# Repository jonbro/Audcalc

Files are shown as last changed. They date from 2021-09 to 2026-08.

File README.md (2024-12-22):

# AudCalc

a pocket sized groovebox.

## Note to folks stumbing across this repo.

I'm happy with this, but its not 100% feature complete on the firmware side. Its really neat though, and I think you'll like it.

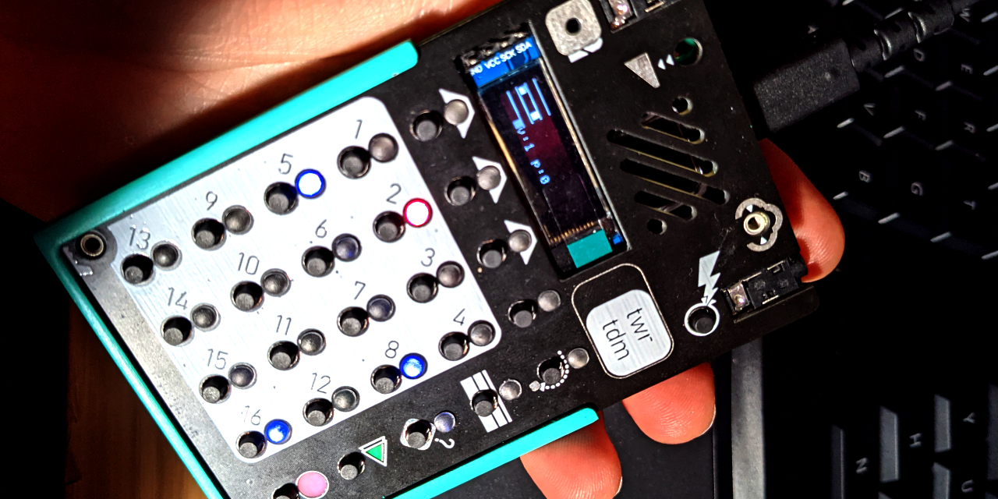
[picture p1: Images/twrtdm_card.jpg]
prototype v6

*v5 prototype*

- RP2040
- 1/8in audio i/o
- onboard mic
- 104mm x 68mm x 14mm

The bom is contained within the Hardware kicad project, ready for assembly via jlcpcb.
There are several additional items that must be sourced and handsoldered:

| part | count | mfg part number | link | notes |
|---|---|---|---|---|
| battery connector | 1 | jst s2b-ph-sm4-tb | https://octopart.com/s2b-ph-sm4-tb%28lf%29%28sn%29-jst-248913 | these are redibly available from aliexpress as well |
| midi / audio jacks | 4 | PJ-327C-4A | https://lcsc.com/product-detail/Audio-Connectors_Korean-Hroparts-Elec-PJ-327C-4A_C145813.html | I believe there is an equivalent CUI headphone jack. I'm using this cheaper version |
| pots | 2 | alps RK09K1130A5R | https://lcsc.com/product-detail/Variable-Resistors-Potentiometers_ALPSALPINE-RK09K1130A5R_C209779.html | |
| oled screen (128x32) | 1 | ssd1306 | https://www.aliexpress.com/item/4000842671330.html | I'm using the white / solderable version. |
| battery | 1 | lp-503562 | https://www.adafruit.com/product/258 | There are other cheaper sources for these. Confirm the correct polarity before using. |
| m2 4mm f-f standoff | 4 | | https://www.aliexpress.com/item/1005002145042844.html | |
| m2 6mm m-f standoff | 4 | | https://www.aliexpress.com/item/1005002145042844.html | |
| m2 3mm hex head bolt (black) | 8 | | https://www.aliexpress.com/item/10000148429238.html | |

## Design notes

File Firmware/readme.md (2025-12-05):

`openocd -f interface/picoprobe.cfg -f target/rp2040.cfg -s tcl`
`cmake -G"NMake Makefiles" ..`
run vscode in developer / admistrator mode for access to nmake (developer command prompt for vs 2019)
check to make sure the "kit" is selected (`GCC for arm-none-eabi 10.2.1`)

picotool save -r 0x10040000 0x11000000 
0x40000 
0x1000000
see this as an option for installing the toolchain
https://github.com/ndabas/pico-setup-windows

<!-- *Resource Generation* -->
`>C:\Python27\python.exe resources_compiler.py resources/resources.py`

*NanoPB generation* 
`python nanopb\generator\nanopb_generator.py VoiceData.proto`
note the forward slashes, it does some kind of replacement on the path to convert to a module name

rates 2x 3/2x 1x 3/4x (triplets) 1/2x 1/4x 1/8x

we want to count up to 0xffffff 8 times per second? at 120bpm

sixteents per second, thirty seconds per second

bpm to bps = 
120 * (1 / 60) * (1/4)

bps to 32nds p sec

bps * 1/8

beats per sample

44100 * 32nds p sec

    "1:1", 1
    
    "1:2", 2
    "2:2", 3 (2*1)
    
    "1:3", 4
    "2:3", 5 
    "1:3", 6 (3*2)

    "1:4", 7
    "2:4", 8
    "3:4", 9
    "4:4", 10 (5*2)
  e

2,756.25
q8          q4
(44100<<8)/(60<<4) = q4

60*32 = 1920

local valTable = {}

for i=2,8 do
  for j=1,i do
   table.insert(valTable, j)
   table.insert(valTable, i)
  end
end

print("const uint8_t ConditionalEvery[".. #valTable .. "] = {\n" .. table.concat(valTable, ", ") .. "};")

        // simplify, lets load from a known good source
        uint32_t filesize = ((uint32_t*)AudioSampleSecondbloop)[0]&0xffffff;
        int16_t* wave = ((int16_t*)AudioSampleSecondbloop)+2;
        if(filesize == 0 || sampleSegment == SMP_COMPLETE)
        {
            memset(buffer, 0, SAMPLES_PER_BUFFER*2);
            return;
        }
        if(sampleOffset > filesize)
            sampleSegment = SMP_COMPLETE;
        if(sampleSegment == SMP_COMPLETE)
            return;
        for(int i=0;i<SAMPLES_PER_BUFFER;i++)
        {
            if(sampleOffset > filesize - 1)
            {
                sampleSegment = SMP_COMPLETE;
            }
            // int16_t wave;
            // ffs_seek(GetFilesystem(), file, sampleOffset*2);
            // ffs_read(GetFilesystem(), file, wave, 2);

            phase_ += phase_increment;
            sampleOffset+=(phase_>>25);
            phase_-=(phase_&(0xfe<<24));

            buffer[i] = wave[sampleOffset];
            
        }
        return;

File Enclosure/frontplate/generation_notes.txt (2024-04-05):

### Frontplate generation notes

sorry, non free software. Hopefully it keeps working for a while. I'll include SVGs of the frontplate so it can continue to be edited.

export the mask and silkscreen groups to pngs that are 5119x7875 (aka 2000dpi)

import into kicad using the image converter tool. Use the output size settings  to 65mm / 100.1mm (set lock height width ratio).

for both images, you will need to use the "negative" button to invert correctly.

in the pcb editor, double click on the footprints, then update from library. You may need to disable layers so you can correctly double click on the soldermask footprint.

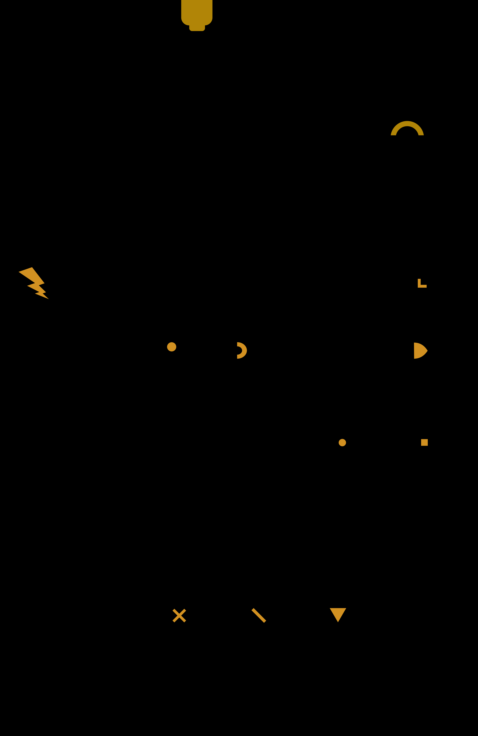
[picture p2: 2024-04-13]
Enclosure/frontplate/frontplate_mask.png

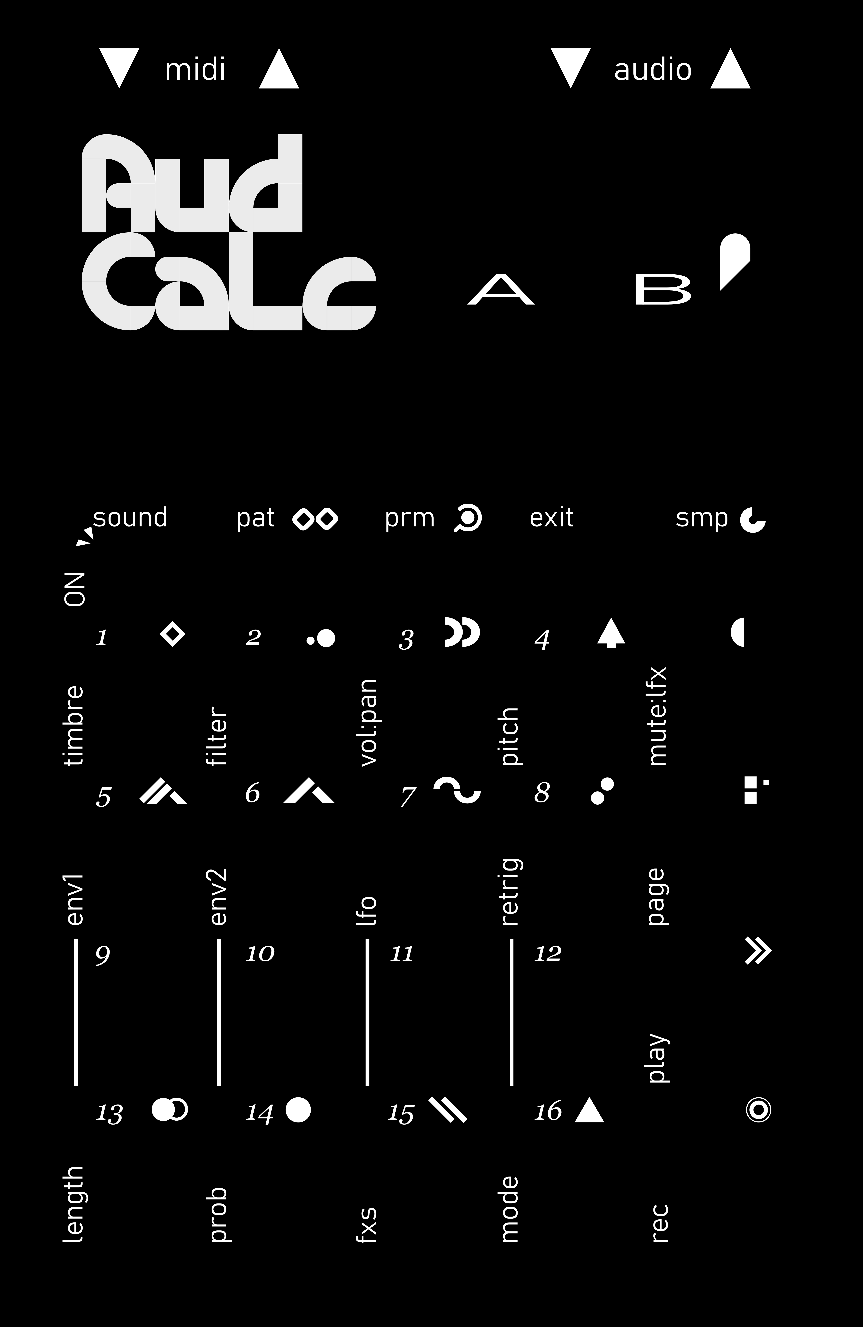
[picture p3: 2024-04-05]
Enclosure/frontplate/frontplate_silk.png

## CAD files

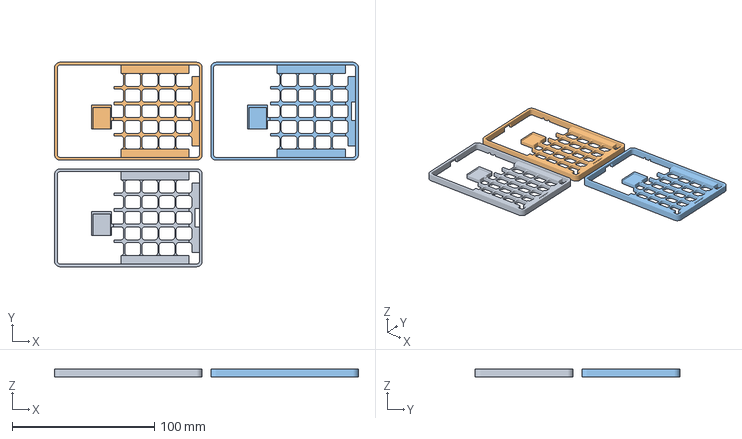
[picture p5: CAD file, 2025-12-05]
Enclosure/printedParts/FrontEnclosure.3mf
214.0 x 144.0 x 5.60 mm

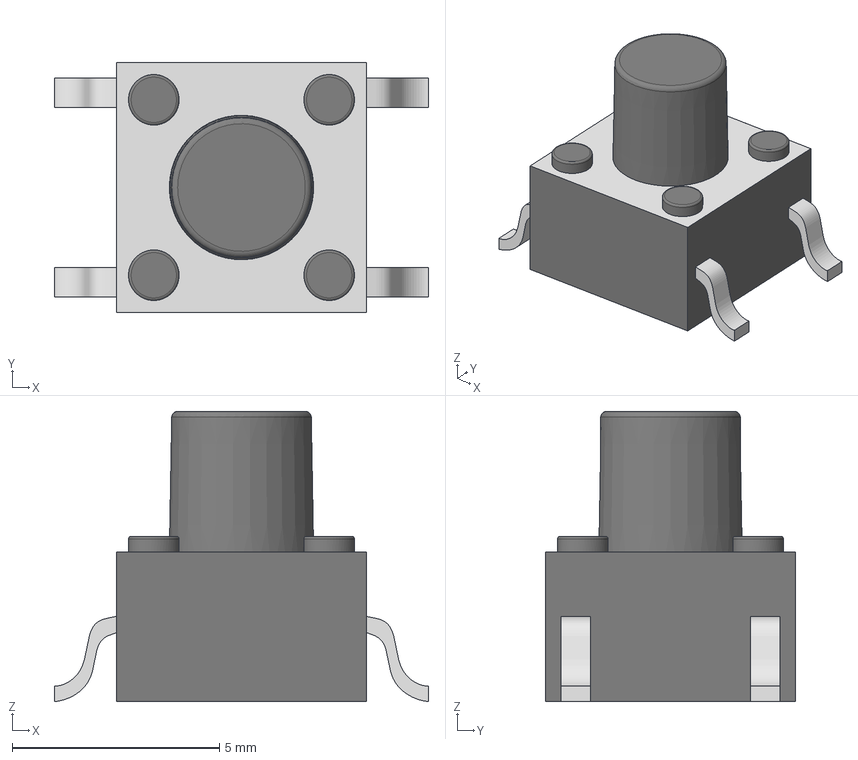
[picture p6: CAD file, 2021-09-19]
Hardware/audcalc/step/Tactal Switch - SMD (6mmx 6mmx 7mm) - Marked.stp
9.02 x 6.03 x 7.00 mm

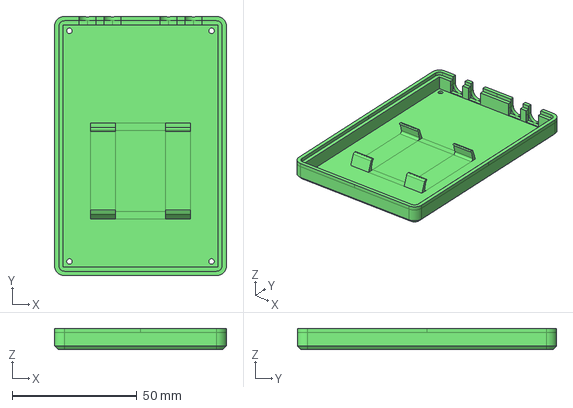
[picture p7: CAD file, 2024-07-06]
Enclosure/printedParts/BackEnclosure.FCStd
69.0 x 104.0 x 8.60 mm

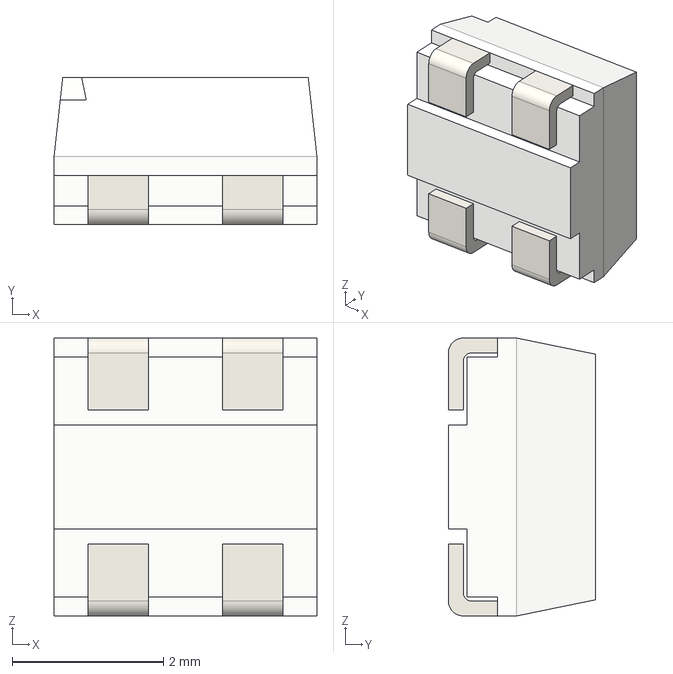
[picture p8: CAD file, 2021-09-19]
Hardware/audcalc/step/SMD WS2812B Mini.step
3.48 x 1.95 x 3.68 mm

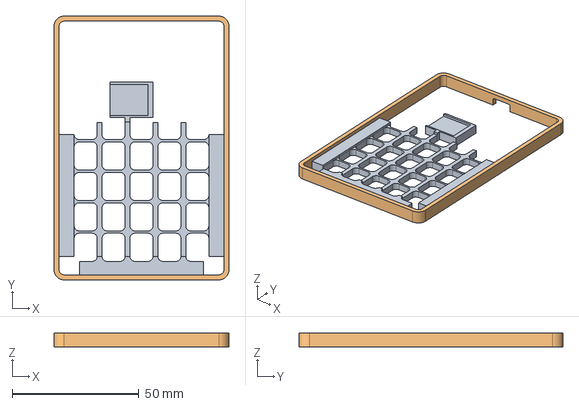
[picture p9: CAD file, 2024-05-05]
Enclosure/printedParts/baffles.FCStd
69.0 x 104.0 x 5.60 mm
baffles screenholder tolerance
outerBorderUsbClip

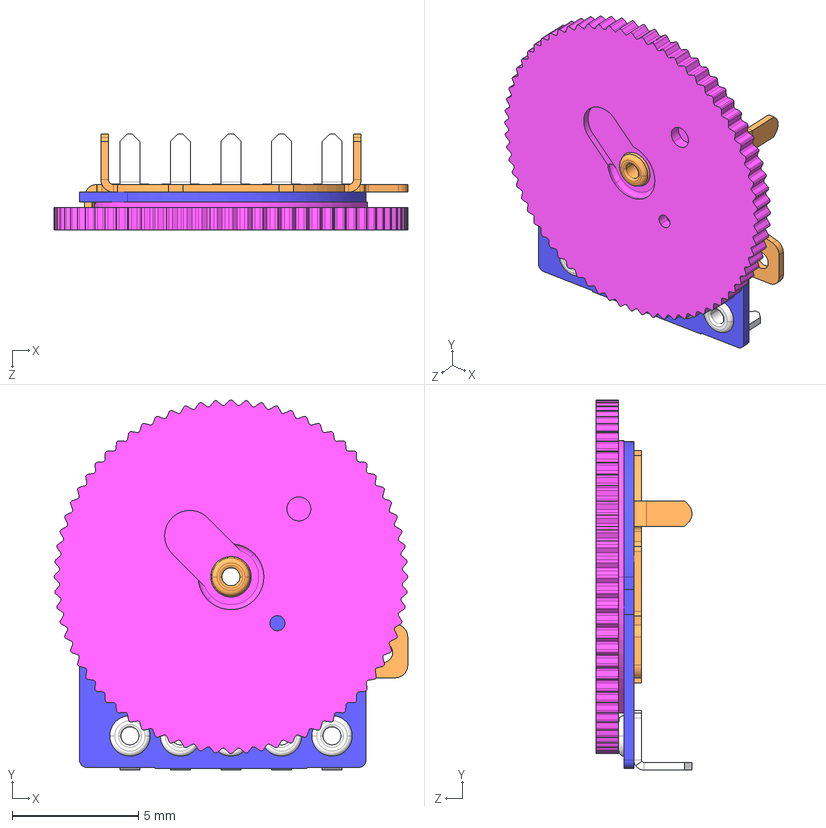
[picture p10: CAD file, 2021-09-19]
Hardware/audcalc/step/RK10J1_E.STEP
14.0 x 14.6 x 3.80 mm

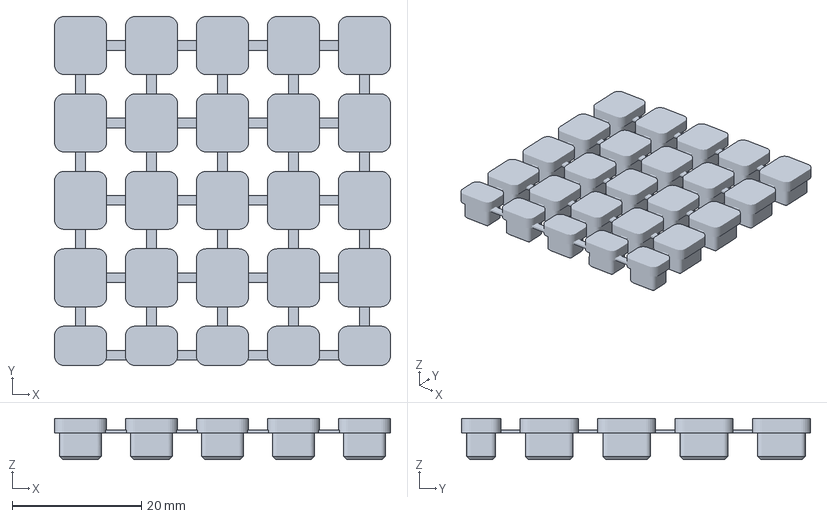
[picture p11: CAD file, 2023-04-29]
Enclosure/printedParts/Buttons.3mf
52.1 x 54.1 x 6.40 mm

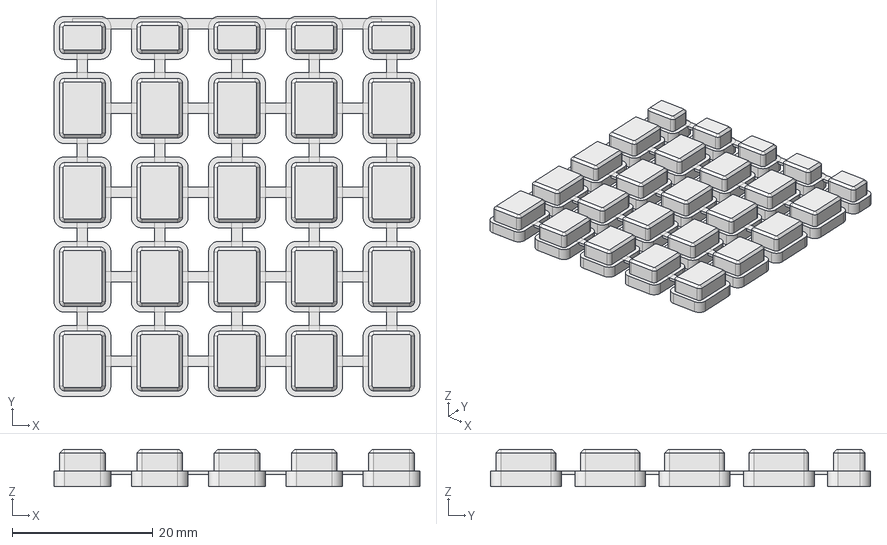
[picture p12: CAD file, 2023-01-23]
Enclosure/printedParts/printedParts-ButtonFrontExtrude.step
52.1 x 54.1 x 5.30 mm

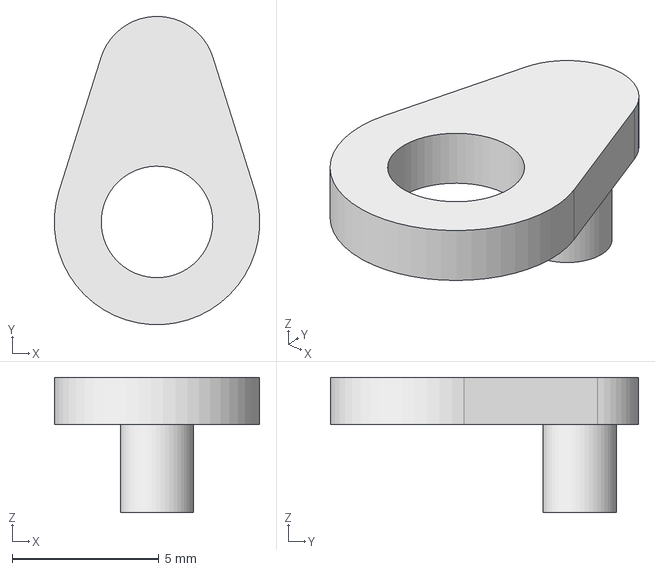
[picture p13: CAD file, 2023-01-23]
Enclosure/printedParts/buttonSurround.step
6.99 x 10.5 x 4.60 mm

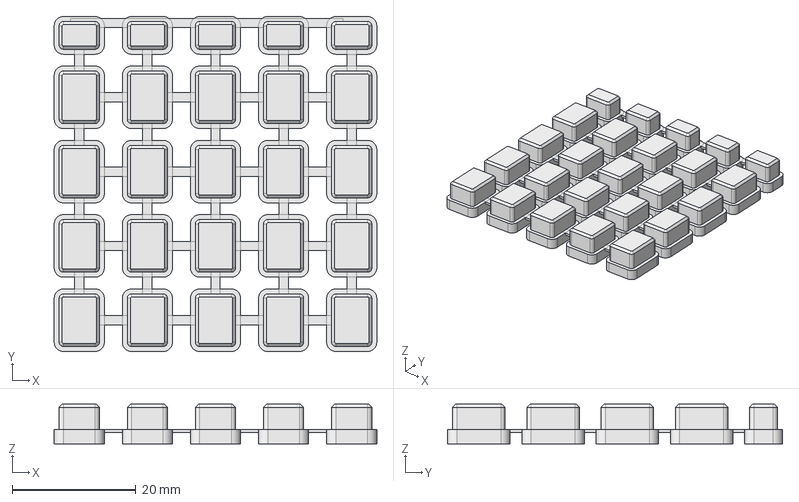
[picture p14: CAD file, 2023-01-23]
Enclosure/printedParts/printedParts-ButtonFrontExtrude-4.1-2.3.step
52.1 x 54.1 x 6.40 mm

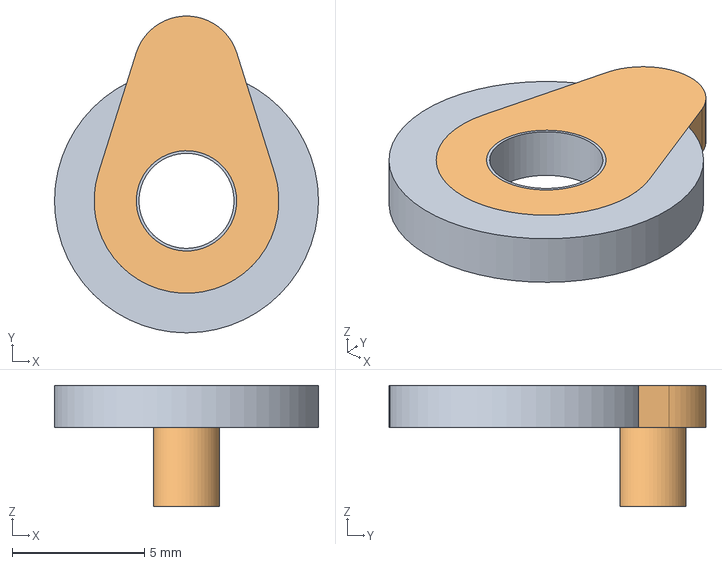
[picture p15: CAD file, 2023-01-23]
Enclosure/printedParts/lightsurroundtest.FCStd
10.0 x 12.0 x 4.60 mm

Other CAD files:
Enclosure/printedParts/printedParts.FCStd
Enclosure/printedParts/BackEnclosure.3mf
Enclosure/printedParts/BackEnclosure.stl
Enclosure/printedParts/Buttons.stl
Enclosure/printedParts/FrontEnclosure.stl

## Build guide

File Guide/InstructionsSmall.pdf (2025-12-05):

# AudCalc

AudCalc is a pocket sequencer and synthesizer with open source firmware. It has 8 high quality synthesis voices, thanks to the cores from mutable instruments braids. The sequencer is advanced for a portable instrument, supporting parameter locks, conditional triggers, and various time signatures and loop lengths. Its fun to jam with by itself, and can link into your larger portable music setup via midi or cv clock.

The firmware, hardware and mechanical design are all are open source. The core chip is the rp2040, which is easily extensible for those that would like to find other uses for audcalc.

Thank you for making noises with AudCalc. Please reach out to jonbro@gmail.com with any questions. The repository with latest firmware and additional notes is available at https://github.com/jonbro/Audcalc/

# Main Keys

ON / sound
Hold ON to power on.
Hold sound + 1-16 key to select the target channel. pat
Hold pat + 1-16 key to select an edit pattern. When playing, the pattern won’t change until the end of the bar. Hold and select multiple patterns to setup a playback chain (up to 16 chain steps)

prm
Hold prm + 1-16 key to select a parameter on the current voice to edit. Some other keys have additional parameters, and some keys have a second page of parameters that can be entered by pressing the key twice while holding prm.

exit
Hold exit + ON to shut down the device. exit + pat to clear the current pattern. exit + smp + 1-16 to clear a sample. smp
Hold smp + 16 to sample

# Sequence Keys

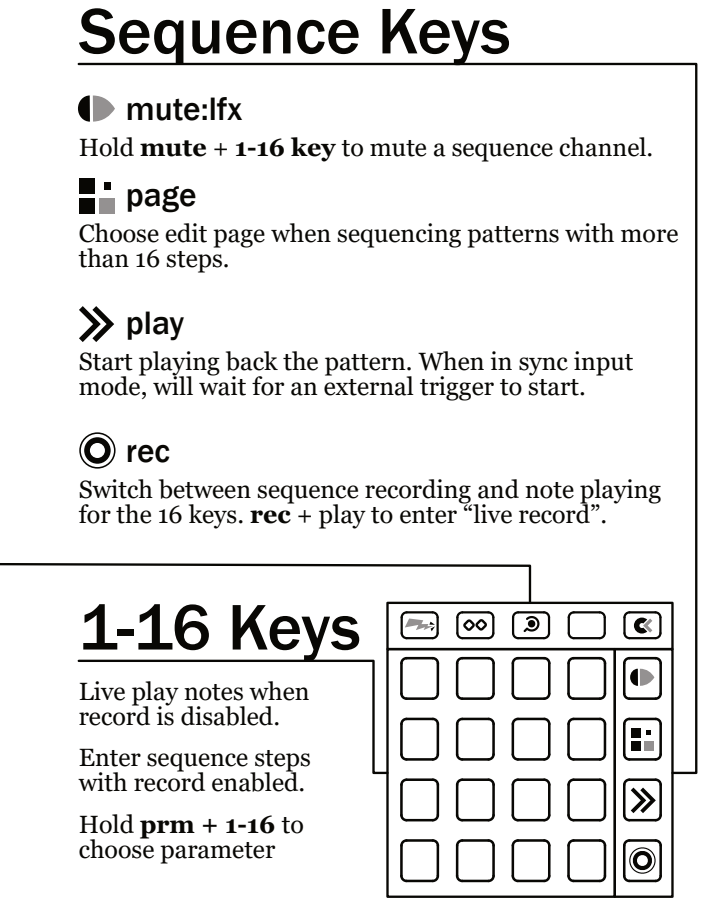
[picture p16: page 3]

mute:lfx
Hold mute + 1-16 key to mute a sequence channel.
page
Choose edit page when sequencing patterns with more
than 16 steps.

play
Start playing back the pattern. When in sync input
mode, will wait for an external trigger to start.

rec
Switch between sequence recording and note playing
for the 16 keys. rec + play to enter “live record”.
1-16 Keys

Live play notes when
record is disabled.
Enter sequence steps
with record enabled.
Hold prm + 1-16 to
choose parameter

# Quick Start: Bleep

Turn On
Hold ON (top left key) to turn on the device.

Play
Press a 1-16 key to play a note. As you are doing further edits, keep pressing the 1-16 keys to hear your sound change.

Edit the Sound
Hold prm + 5 (env1) then turn the B knob to increase the decay on the sound. It should ring out for longer.

Wobble
Hold prm + 11 (Lfo Target), then choose Cut to route the LFO to cutoff. Hold prm + 7, then edit the Rate and Depth to change the wobble amount.

Main Osc
Hold prm + 16 (Mode), then choose Synth with the A knob, and WMAP with the B knob. Hold prm + 1 (timbre) then edit the sound with the A + B knobs.

# Quick Start: Repeat

Step Record
Press the rec key (lower right) to enter record mode. Now Press the 1-16 keys to set the current note to play on those steps. Press play (above rec key) to hear the pattern playback.

Live Record
Exit play mode, then hold rec + press play. This will enter live write (play button will light up red). Press the 1-16 keys to enter notes live.

Conditional triggers
Hold prm + 14 (prob) then use A to set Rnd and B to set the percentage of notes that will play randomly.

Parameter Lock Live Record
Hold prm + 2 (Filter) to enter cutoff editing. Hold down the rec key and twist the A knob to store a live filter cutoff sequence.

Parameter Lock step
Hold prm + 15 (Fxs). Make sure write is on (rec key is red) but live write is off (play is green or unlit). Hold down a step that has a note recorded (the 1-16 key is purple). While holding this key rotate A knob to increase the delay fx send for this step.

# Parameters

Hold prm & press one of the 1-16 buttons to select a parameter. When a parameter is selected, it will be displayed onscreen, and using the a/b knobs will edit it. Most parameters apply to the voice across all patterns, except as noted.
Note:
Some parameters have a second page, which is accessed by holding prm & pressing the 1-16 button a second time while already on this page.

### 5 Envelope 1 This envelope is always routed to

volume, but can be routed to a second target additionally.

### 6 Envelope 2 This envelope is unrouted by

default. It can be routed to a single target.

### 9 Envelope 1 Destination + Depth An

additional routing for the Env. Depth is how much the envelope effects the parameter.

### 10 Envelope 2 Destination + Depth

### 1 Timbre / Color when in synth mode, this affects

the voice. In Sample mode this changes sample in / out points. In midi mode this edits velocity & hold time.

### 2 Filter Cutoff & Resonance lowpass filter

### 3 Volume / Pan

### 4 Legato / Fine Tune legato affects pitch slide

### 7 LFO The LFO speed is derived from the current

tempo, so changing the tempo will alter this speed.

11 LFO destination Destination for the lfo.

8 Retrigger speed & length - Lower speeds are faster. Length is how many retriggers there will be.

### 12 Retrigger decay if the retriggers fade in (negative)

or fade out (positive)

### 13 Pattern Length how many steps this voice uses on

this pattern, and how fast each step is. This can be set per voice per pattern. When editing this parameter, press prm+13 again to double the pattern length

### 14 Probability Rnd sets a random probability for each

step (or an individual step is set via parameter locks). Len sets a number of time the step plays per pass through the pattern. For example 1:3 will play on the first pass through the pattern, every 3 times through the pattern.

### 15 Effect sends Delay and reverb sends. Press prm a

second time to access delay settings. The delay is a simple digital buffer, so live edits will introduce glitches.

### 16 Voice Mode Set the

synth mode for this
channel. Choose between
Synth, Sample, and MIDI.
See next page for details.

# Voice Mode

Under the voice mode parameter (16) - there are three submodes, each with several options. Access the primary mode via the A knob, and the secondary mode via the B knob.

synt has many voices underneath it, these are generally synthesized and wave table sounds. These voices are a subset from mutable instruments braids, detailed listings are available online.

samp voice has a slice, pitch, and loop length sync option.

midi voice allows each channel to send midi note data out. Midi data is sent simultaneously to the usb and trs midi. Midi channel for the voice is selected here.

# Special Parameters

prm+ pat: Pattern change length During playback, when you change pattern, it will wait until the end of this bar length before changing patterns. Useful if you want to change every four measures.

prm+ play: Bpm & sync options Sync can be set to PO (pocket operator, volca, 2 pulses per quarter note), 4PQ (4 pulses per quarter note), Midi, or a combination of midi & one of the other two. Press a second time to access Sync Out settings.

prm+ rec: Root note & scale Octave and root note apply to the 1-16 buttons. Press a second time to access different scales. These settings will not change existing recorded notes.

# Sequencing

There are two ways to record notes into a pattern, step mode & live mode.

Step Mode
While write is not lit, choose a note by pressing a button 1-16. Then press write to enter write mode. Pressing buttons 1-16 will enter the last selected note on those steps.

Live Mode
While write is not lit, and the pattern is not playing, hold write, then press play. Once in live mode, notes played using the buttons 1-16 will be stored in the current pattern.

Parameter Lock
While in step mode, hold down a lit step and move a knob to store a parameter lock for that step. There are 128*16 parameter locks available.

While in playback, holding down record and moving a knob will store parameter locks for playing steps as it passes.

Edit Page
To change the page you are currently editing for the pattern, press the page button. This only applies if the pattern has more than 16 steps.

# Edit Controls

Copy Voice
Hold rec + sound + 1-16 to copy the current voice to a different channel. This will overwrite the voice in this channel.

Copy Pattern
Hold rec + pat + 1-16 to copy the current pattern to a different pattern.

Erase Pattern
Hold exit + pat to erase the current pattern.

Erase Voice
Hold Exit + prm to erase the current Voice.

# Technical Notes

Voice stealing
There are 8 voices, but 16 sequence channels. Voices are grouped in pairs, 1-5, 2-6, 9-13 and so on. Voices will be muted when a voice from their pair starts playing. This does not apply to midi channels.

Startup in usb boot
Hold rec while plugging in usb (from device off) to enter usb boot mode. This allows you to flash new firmware. There are also two small buttons on the right of the unit. The top is uboot, and the bottom is reset. Hold the top one, then press the bottom to reboot in USB mode if all else fails.

Sample Rate / Bit depth
Internal sample rate is 32Khz, bit depth is 16 or 32 bits fixed point depending on synthesis stage.

Clock input
The clock sync can be driven in PO mode (pulse per 1/8th note) or volca (pulse per 1/16th note). The audio input has protection diodes, and will clamp input voltages.

If there is crosstalk with loud clock signals, use the included attenuator to lower the volume of the signal.

# Open Source

Audcalc would not have been possible without tons of open source software. AudCalc also open source and is permissively licensed where possible. Full license details are on https://github.com/jonbro/Audcalc/

Auto Crossover Midi input
circuit is used with permission
from kay / lpzw modules - https://leipzigwest.org

M6x11 is free to use with
attribution by Daniel Linssen -https://managore.itch.io/m6x11

ZLib/libpng licence covers the following portions of the code Nanopb Copyright (c) 2011
Petteri Aimonen

The MIT License covers the following portions of the code SSD1306 rp2040 driver
Copyright (c) 2021 David
Schramm

Braids Copyright 2012 Emilie Gillet (emilie.o.gillet@gmail.com)

TinyUsb

Copyright (c) 2019 Ha Thach (tinyusb.org)

Copyright (c) 2020 Jerzy
Kasenbreg

Software License Agreement (BSD License) covers the
following portions of the code gfx_font Copyright (c) 2012

Adafruit Industries. All rights reserved.

BSD 3-Clause "New" or "Revised" License covers the following portions of the code
ws2812 driver Copyright 2020
(c) 2020 Raspberry Pi (Trading) Ltd.

Apache license v2 covers the following portions of the code q15 math Copyright (C) 2010-2022 ARM Limited or its affiliates. All rights reserved.

Christophe Favergeon

Auto Crossover Midi input
circuit is used with permission from kay / lpzw modules - https://leipzigwest.org

M6x11 is free to use with
attribution by Daniel Linssen -https://managore.itch.io/m6x11

ZLib/libpng licence covers the following portions of the code Nanopb Copyright (c) 2011 Petteri Aimonen

The MIT License covers the following portions of the code SSD1306 rp2040 driver
Copyright (c) 2021 David Schramm

Braids Copyright 2012 Emilie Gillet (emilie.o.gillet@gmail.com)

TinyUsb

Copyright (c) 2019 Ha Thach (tinyusb.org)

Copyright (c) 2020 Jerzy
Kasenbreg

Software License Agreement (BSD License) covers the following portions of the code
gfx_font Copyright (c) 2012 Adafruit Industries. All rights reserved.

BSD 3-Clause "New" or "Revised" License covers the following portions of the code
ws2812 driver Copyright 2020
(c) 2020 Raspberry Pi (Trading) Ltd.

Apache license v2 covers the following portions of the code q15 math Copyright (C) 2010-2022 ARM Limited or its affiliates. All rights reserved.

Christophe Favergeon

# Additional Thanks

Morgan & Ziv thanks for letting me play with this stuff so much. Its been a journey.

The Plinky Discord What a weird feral synth chat room. Wouldn’t have been possible without you.

# Specs

Midi in (trs a or b)/ out (trs a)
Usb charging and Usb midi
Audio in / out (audio click sync on left channel)
32x128 oled screen
2 potentiometers for data input
16 sequencing channels with 8 synthesized voices, or 16 midi out voices
16 patterns with 4096 pattern locks. Patterns support 1-64 steps, with conditional triggers
Sampling from audio in or onboard mic

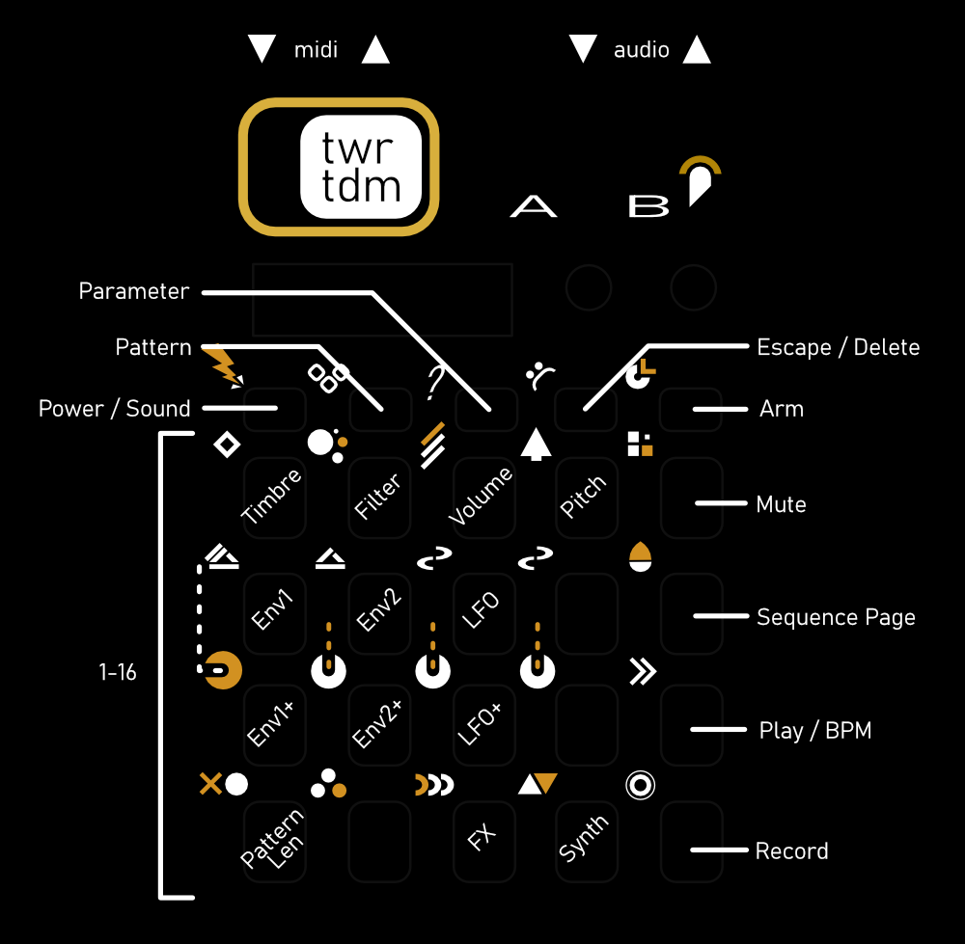
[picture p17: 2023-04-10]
Guide/layout.png

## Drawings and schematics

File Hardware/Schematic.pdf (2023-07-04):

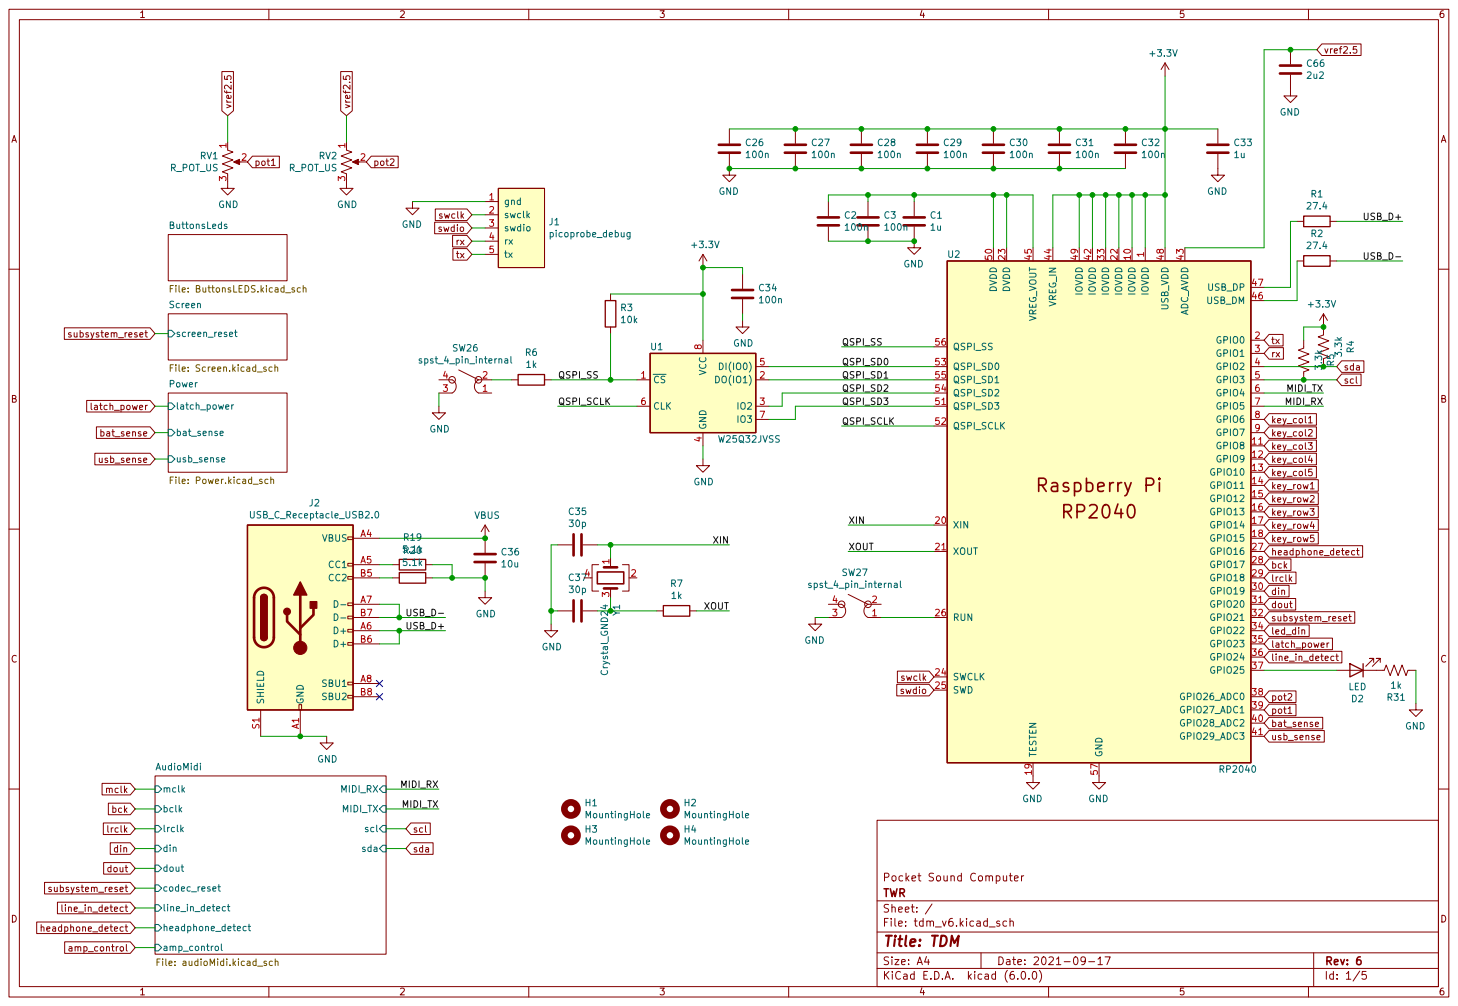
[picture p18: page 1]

1 IOVDD 10 GPIO8 11 GPIO9 12 GPIO10 13 GPIO11 14 GPIO12 15 GPIO13 16 GPIO14 17 GPIO15 18 TESTEN 19 GPIO0 2 XIN 20 XOUT 21 IOVDD 22 DVDD 23 SWCLK 24 SWD 25 RUN 26 GPIO16 27 GPIO17 28 GPIO18 29 GPIO1 3 GPIO19 30 GPIO20 31 GPIO21 32 IOVDD 33 GPIO22 34 GPIO23 35 GPIO24 36 GPIO25 37 GPIO26_ADC0 38 GPIO27_ADC1 39 GPIO2 4 GPIO28_ADC2 40 GPIO29_ADC3 41 IOVDD 42 ADC_AVDD 43 VREG_IN 44 VREG_VOUT 45 USB_DM 46 USB_DP 47 USB_VDD 48 IOVDD 49 GPIO3 5 DVDD 50 QSPI_SD3 51 QSPI_SCLK 52 QSPI_SD0 53 QSPI_SD2 54 QSPI_SD1 55 QSPI_SS 56 GND 57 GPIO4 6 GPIO5 7 GPIO6 8 GPIO7 9 U2 RP2040

amp_control AudioMidi File: audioMidi.kicad_sch
bck mclk dout din

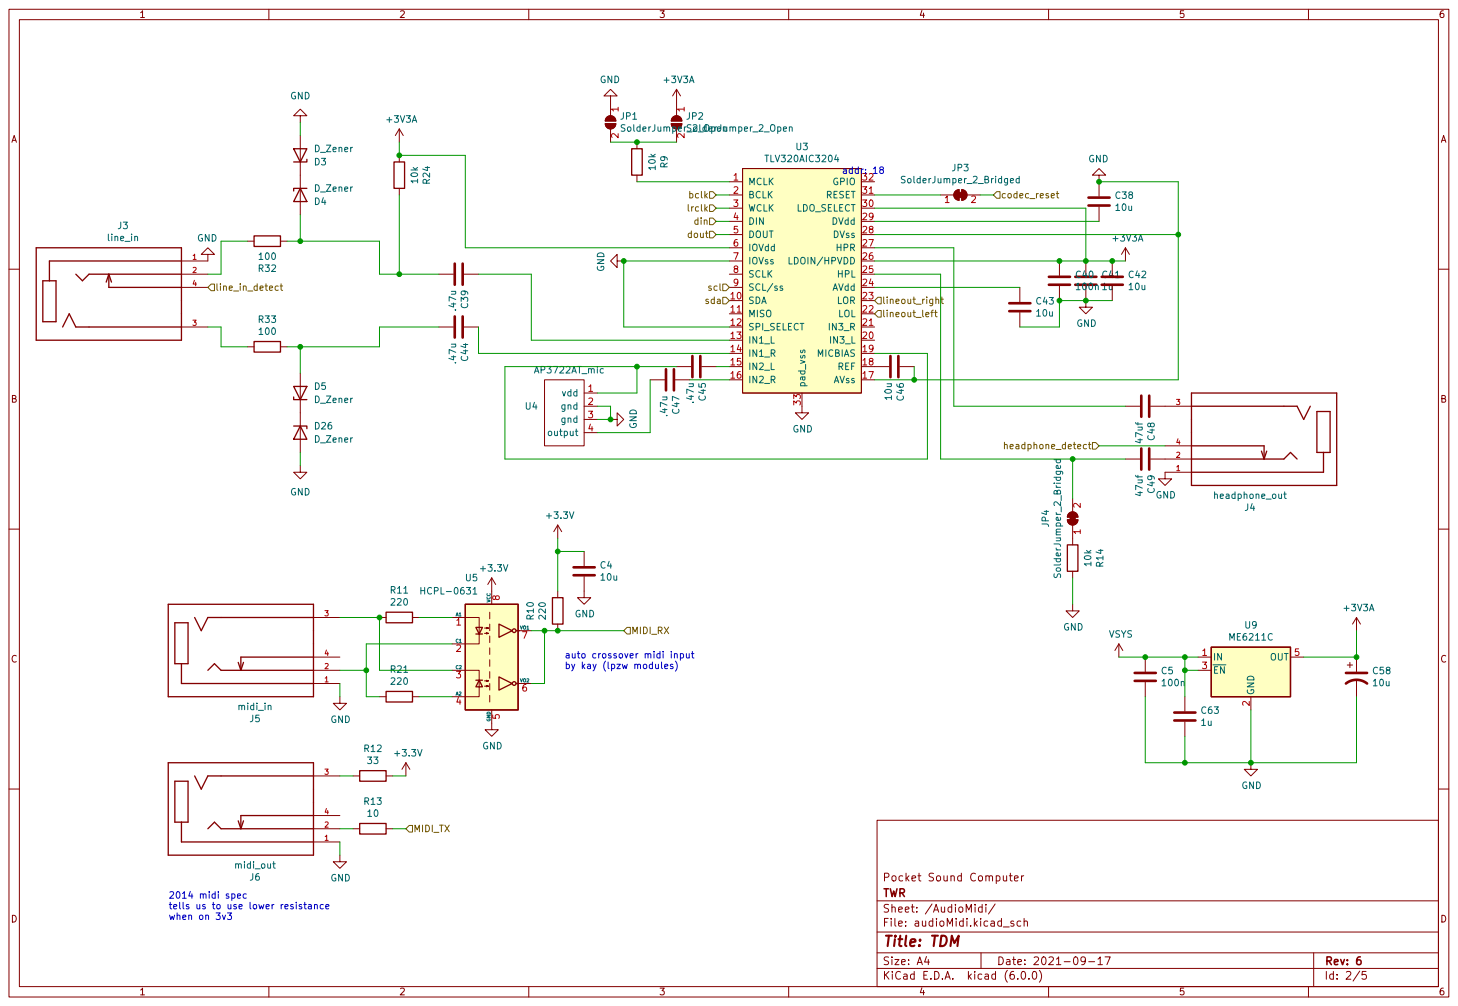
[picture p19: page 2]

lrclk auto crossover midi input

by kay (lpzw modules)

Pocket Sound Computer
File: audioMidi.kicad_sch Sheet: /AudioMidi/ TWR

2014 midi spec
tells us to use lower resistance when on 3v3

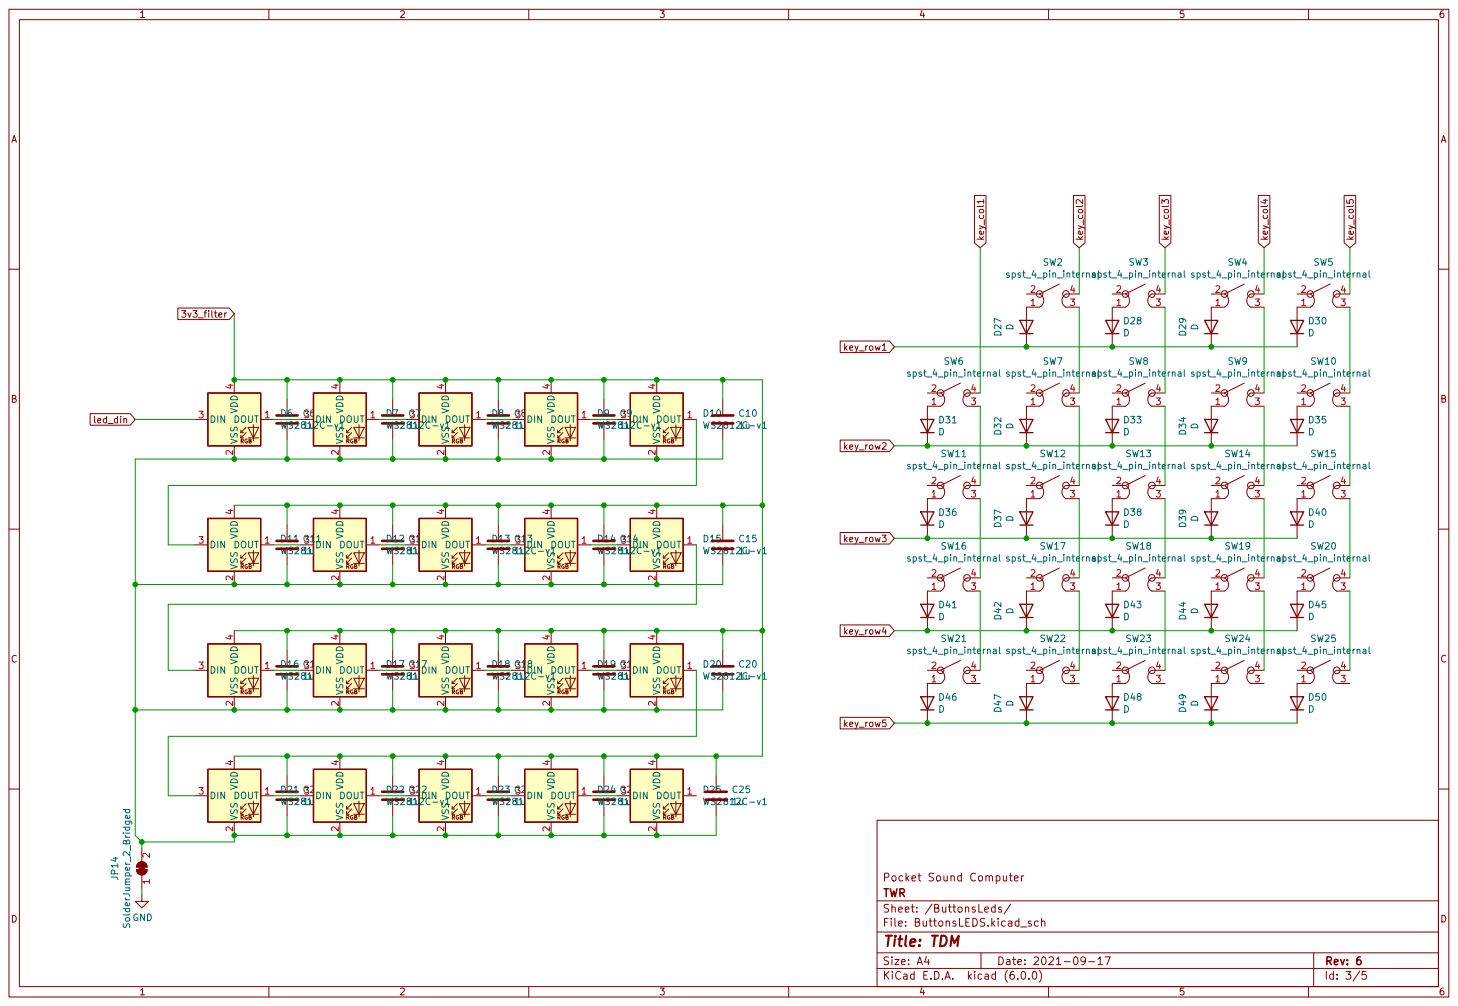
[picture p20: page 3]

File: ButtonsLEDS.kicad_sch Sheet: /ButtonsLeds/ TWR

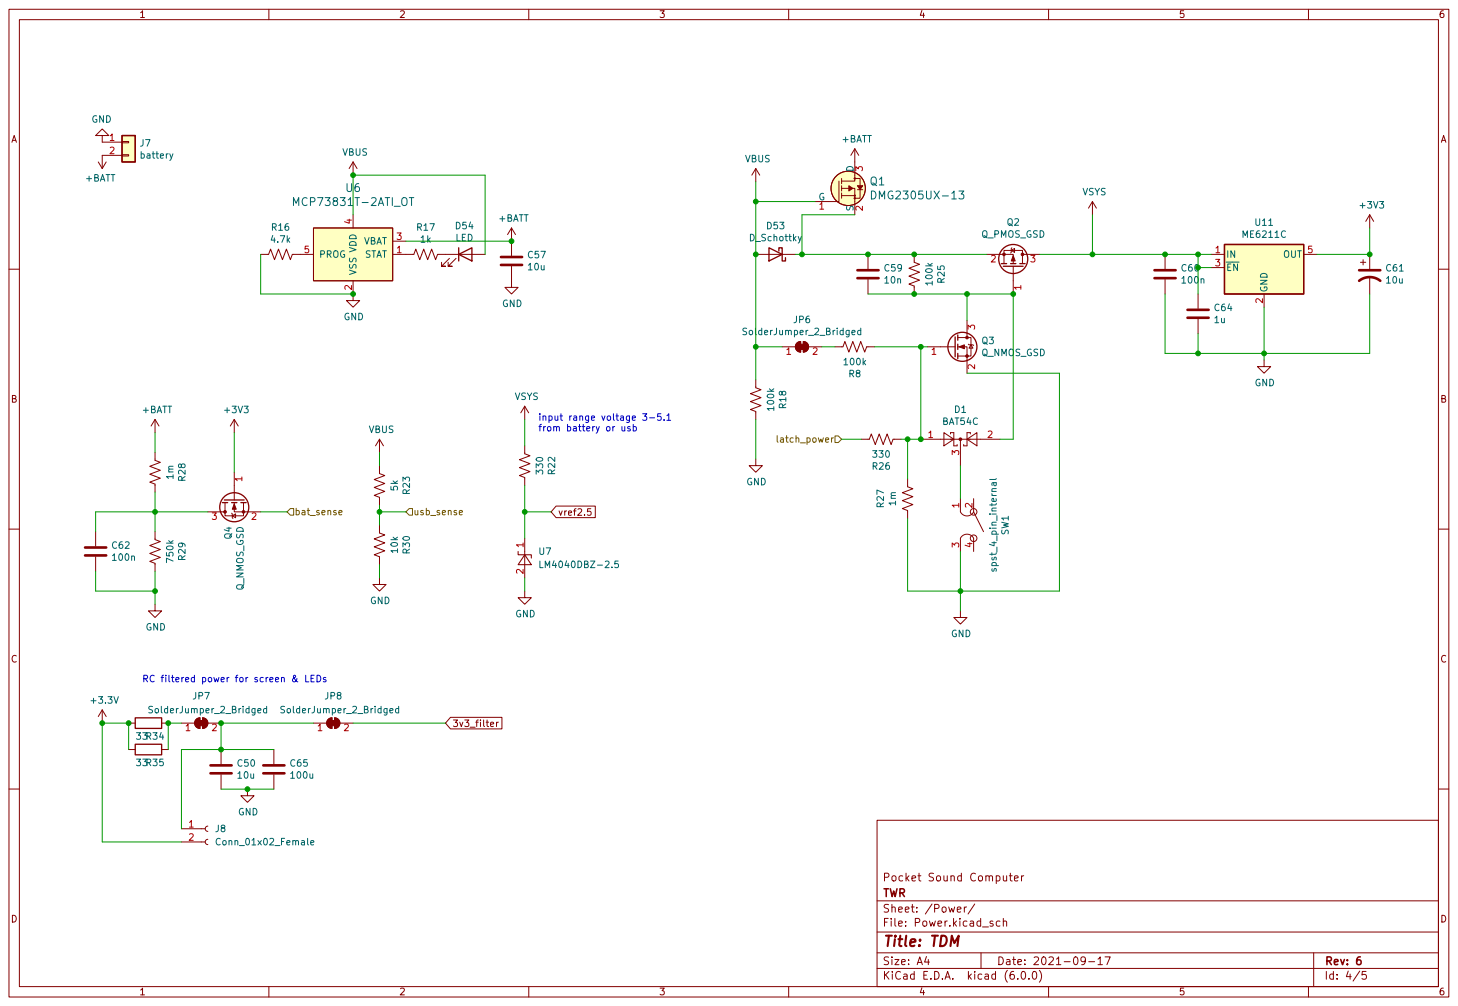
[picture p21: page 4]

input range voltage 3-5.1
from battery or usb

RC filtered power for screen & LEDs
JP7 SolderJumper_2_Bridged

Pocket Sound Computer
File: Power.kicad_sch Sheet: /Power/ TWR

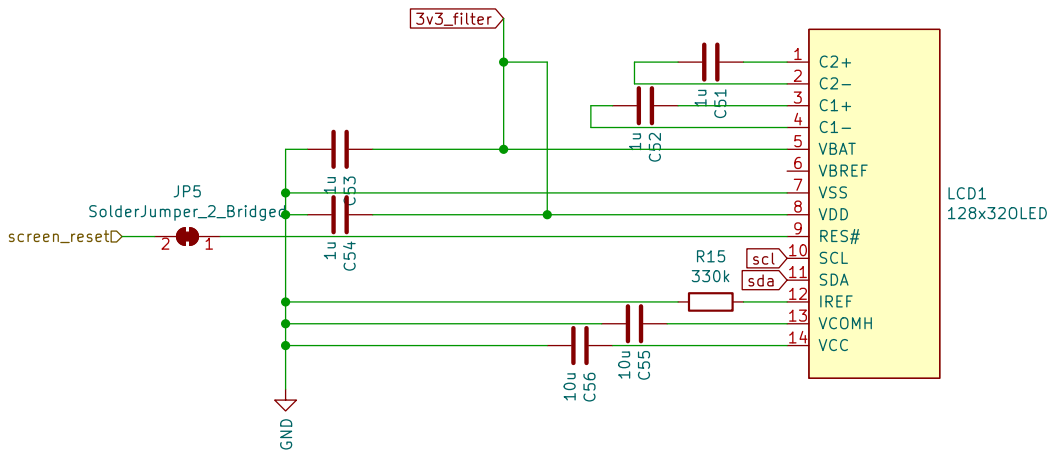
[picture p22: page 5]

Pocket Sound Computer 10u C56 C531u GND

File: Screen.kicad_sch Sheet: /Screen/ TWR

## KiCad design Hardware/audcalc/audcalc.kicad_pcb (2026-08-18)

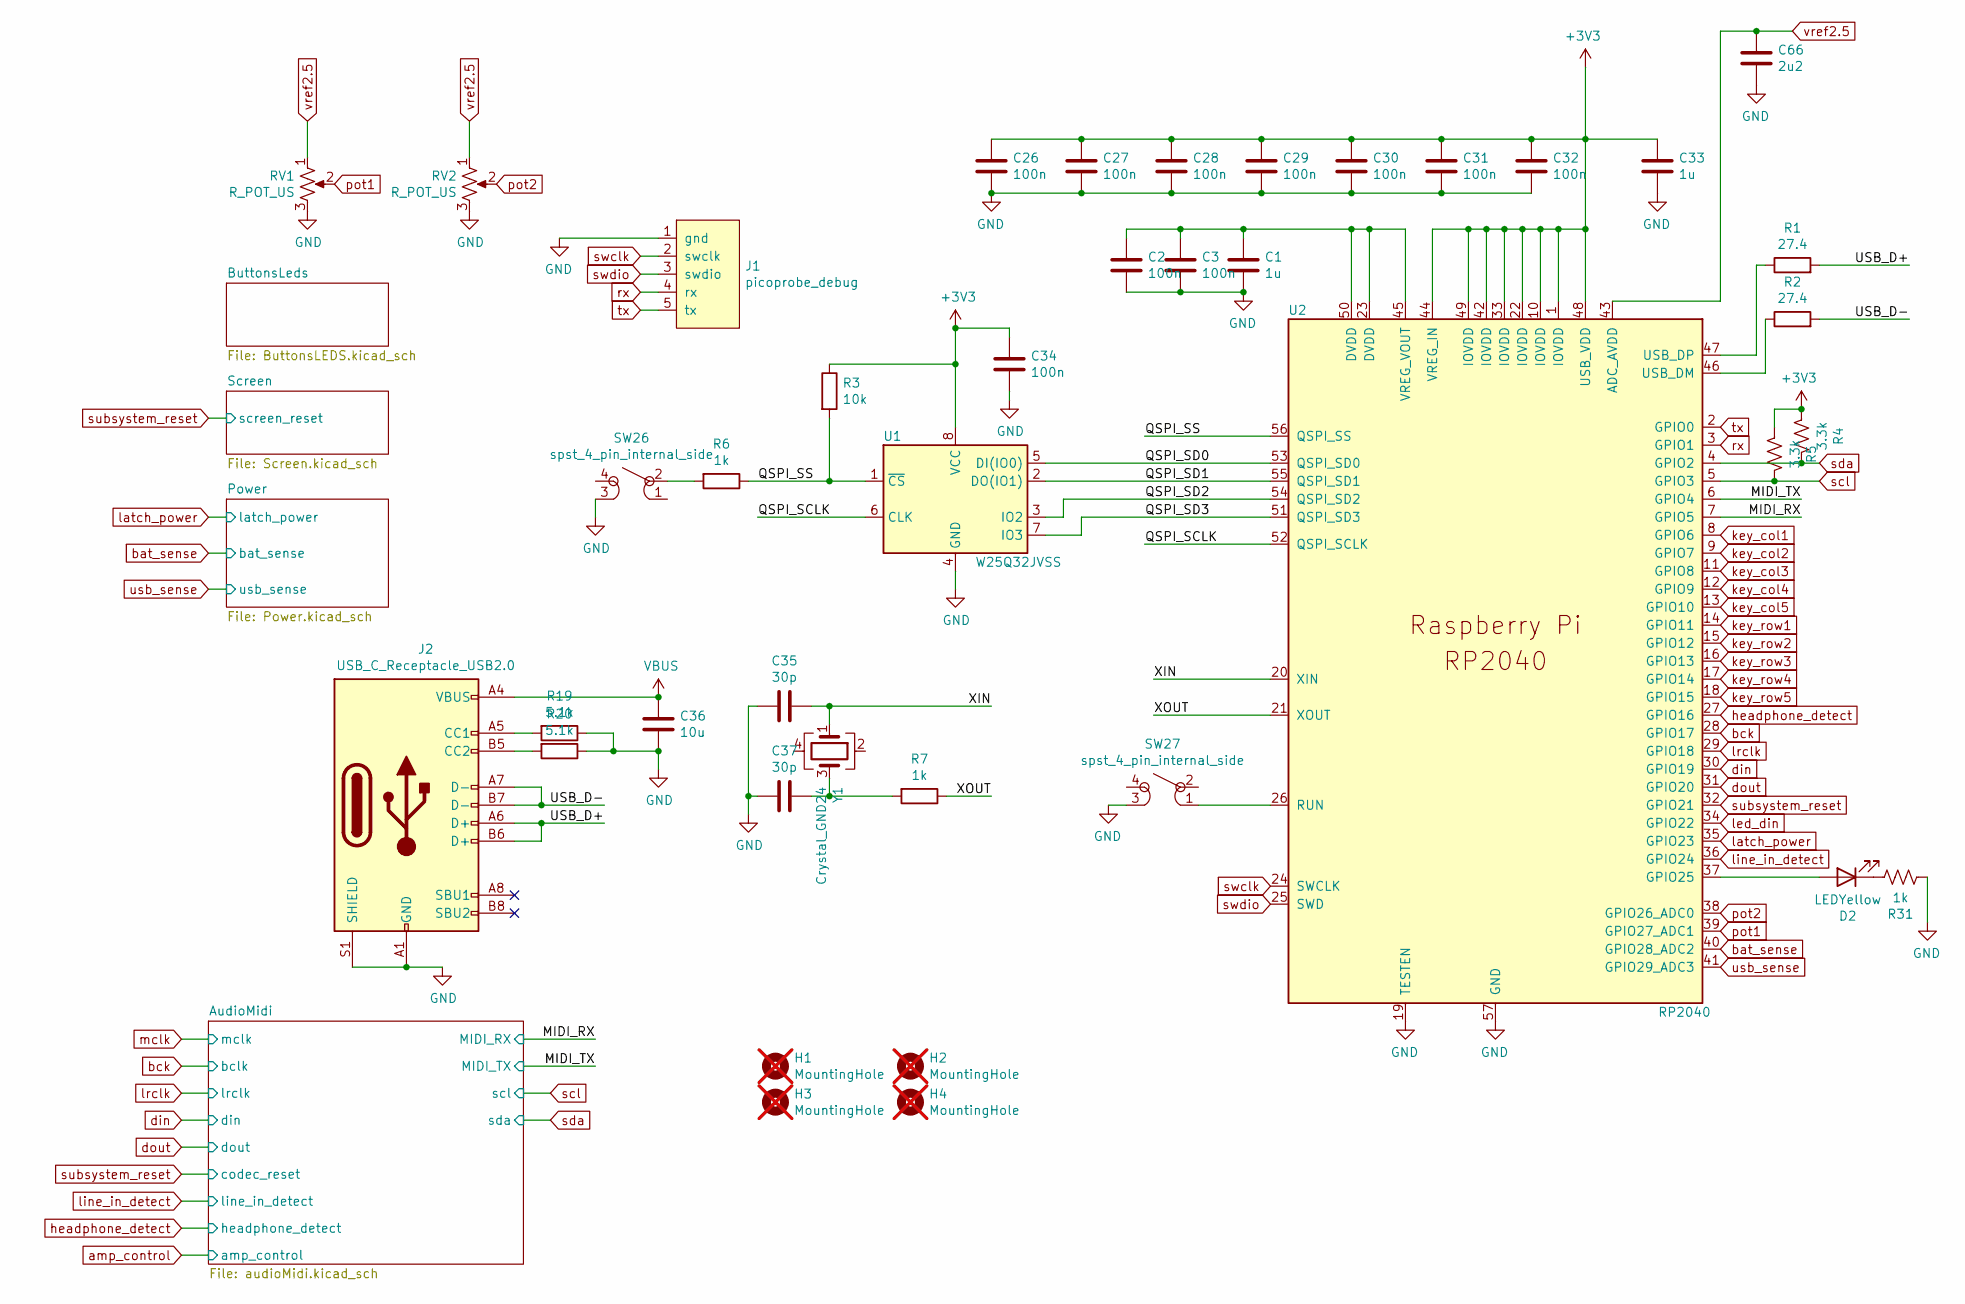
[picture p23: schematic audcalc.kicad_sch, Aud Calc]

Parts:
C1, C33: 1u; C_0402_1005Metric; LCSC C52923
C2, C3, C26, C27, C28, C29, C30, C31, C32, C34: 100n; C_0402_1005Metric; LCSC C307331
C35, C37: 30p; C_0402_1005Metric; LCSC C1570
C36: 10u; C_0402_1005Metric; LCSC C15525
C66: 2u2; C_0402_1005Metric; LCSC C12530
D2: LEDYellow; LED_0603; LCSC C89811
H1, H2, H3, H4: MountingHole; MountingHole_2.2mm_M2; not fitted
J1: picoprobe_debug; pico debug header
J2: USB_C_Receptacle_USB2.0; USB-C_SMD-TYPE-C-31-M-12; LCSC C165948
R1, R2: 27.4; R_0402_1005Metric_nosilk; LCSC C31439
R3: 10k; R_0402_1005Metric_nosilk; LCSC C25744
R4, R5: 3.3k; R_0402_1005Metric_nosilk; LCSC C25890
R6, R7, R31: 1k; R_0402_1005Metric_nosilk; LCSC C11702
R19, R20: 5.1k; R_0402_1005Metric_nosilk; LCSC C25905
RV1, RV2: R_POT_US; Potentiometer_Alps_RK09K_Horizontal; LCSC C209779
SW26, SW27: spst_4_pin_internal_side; SKSCLDE010; LCSC C115362
U1: W25Q32JVSS; SOIJ-8_5.3x5.3mm_Pitch1.27mm; LCSC C97521
U2: RP2040; RP2040-QFN-56; LCSC C2040
Y1: Crystal_GND24; Crystal_SMD_3225-4pin_3.2x2.5mm; LCSC C5332006

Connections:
+3V3: C26.1, C27.1, C28.1, C29.1, C30.1, C31.1, C32.1, C33.1, C34.1, R3.1, R4.1, R5.1, U1.8 (VCC), U2.1 (IOVDD), U2.10 (IOVDD), U2.22 (IOVDD), U2.33 (IOVDD), U2.42 (IOVDD), U2.44 (VREG_IN), U2.48 (USB_VDD), U2.49 (IOVDD); also elsewhere on the board
/MIDI_RX: U2.7 (GPIO5); also elsewhere on the board
/MIDI_TX: U2.6 (GPIO4); also elsewhere on the board
/QSPI_SCLK: U1.6 (CLK), U2.52 (QSPI_SCLK)
/QSPI_SD0: U1.5 (DI(IO0)), U2.53 (QSPI_SD0)
/QSPI_SD1: U1.2 (DO(IO1)), U2.55 (QSPI_SD1)
/QSPI_SD2: U1.3 (IO2), U2.54 (QSPI_SD2)
/QSPI_SD3: U1.7 (IO3), U2.51 (QSPI_SD3)
/QSPI_SS: R3.2, R6.1, U1.1 (~CS), U2.56 (QSPI_SS)
/USB_D+: J2.A6 (D+), J2.B6 (D+), R1.2
/USB_D-: J2.A7 (D-), J2.B7 (D-), R2.2
/XIN: C35.1, U2.20 (XIN), Y1.1
/XOUT: R7.1, U2.21 (XOUT)
GND: C1.2, C2.2, C3.2, C26.2, C27.2, C28.2, C29.2, C30.2, C31.2, C32.2, C33.2, C34.2, C35.2, C36.2, C37.2, C66.2, J1.1 (gnd), J2.A1 (GND), J2.A12 (GND), J2.B1 (GND), J2.B12 (GND), J2.S1 (SHIELD), R19.1, R20.1, R31.2, RV1.3, RV2.3, SW26.3, SW27.3, U1.4 (GND), U2.19 (TESTEN), U2.57 (GND); also elsewhere on the board
unnamed: C37.1, R7.2, Y1.3
unnamed: D2.2 (A), U2.37 (GPIO25)
unnamed: D2.1 (K), R31.1
unnamed: J2.A5 (CC1), R19.2
unnamed: J2.B5 (CC2), R20.2
unnamed: R6.2, SW26.2
unnamed: SW27.1, U2.26 (RUN)
unnamed: R2.1, U2.46 (USB_DM)
unnamed: R1.1, U2.47 (USB_DP)
unnamed: C1.1, C2.1, C3.1, U2.23 (DVDD), U2.45 (VREG_VOUT), U2.50 (DVDD)
VBUS: C36.1, J2.A4 (VBUS), J2.A9 (VBUS), J2.B4 (VBUS), J2.B9 (VBUS); also elsewhere on the board
bat_sense: U2.40 (GPIO28_ADC2); also elsewhere on the board
bck: U2.28 (GPIO17); also elsewhere on the board
din: U2.30 (GPIO19); also elsewhere on the board
dout: U2.31 (GPIO20); also elsewhere on the board
headphone_detect: U2.27 (GPIO16); also elsewhere on the board
key_col1: U2.8 (GPIO6); also elsewhere on the board
key_col2: U2.9 (GPIO7); also elsewhere on the board
key_col3: U2.11 (GPIO8); also elsewhere on the board
key_col4: U2.12 (GPIO9); also elsewhere on the board
key_col5: U2.13 (GPIO10); also elsewhere on the board
key_row1: U2.14 (GPIO11); also elsewhere on the board
key_row2: U2.15 (GPIO12); also elsewhere on the board
key_row3: U2.16 (GPIO13); also elsewhere on the board
key_row4: U2.17 (GPIO14); also elsewhere on the board
key_row5: U2.18 (GPIO15); also elsewhere on the board
latch_power: U2.35 (GPIO23); also elsewhere on the board
led_din: U2.34 (GPIO22); also elsewhere on the board
line_in_detect: U2.36 (GPIO24); also elsewhere on the board
lrclk: U2.29 (GPIO18); also elsewhere on the board
pot1: RV1.2, U2.39 (GPIO27_ADC1)
pot2: RV2.2, U2.38 (GPIO26_ADC0)
rx: J1.4 (rx), U2.3 (GPIO1)
scl: R5.2, U2.5 (GPIO3); also elsewhere on the board
sda: R4.2, U2.4 (GPIO2); also elsewhere on the board
subsystem_reset: U2.32 (GPIO21); also elsewhere on the board
swclk: J1.2 (swclk), U2.24 (SWCLK)
swdio: J1.3 (swdio), U2.25 (SWD)
tx: J1.5 (tx), U2.2 (GPIO0)
usb_sense: U2.41 (GPIO29_ADC3); also elsewhere on the board
vref2.5: C66.1, RV1.1, RV2.1, U2.43 (ADC_AVDD); also elsewhere on the board

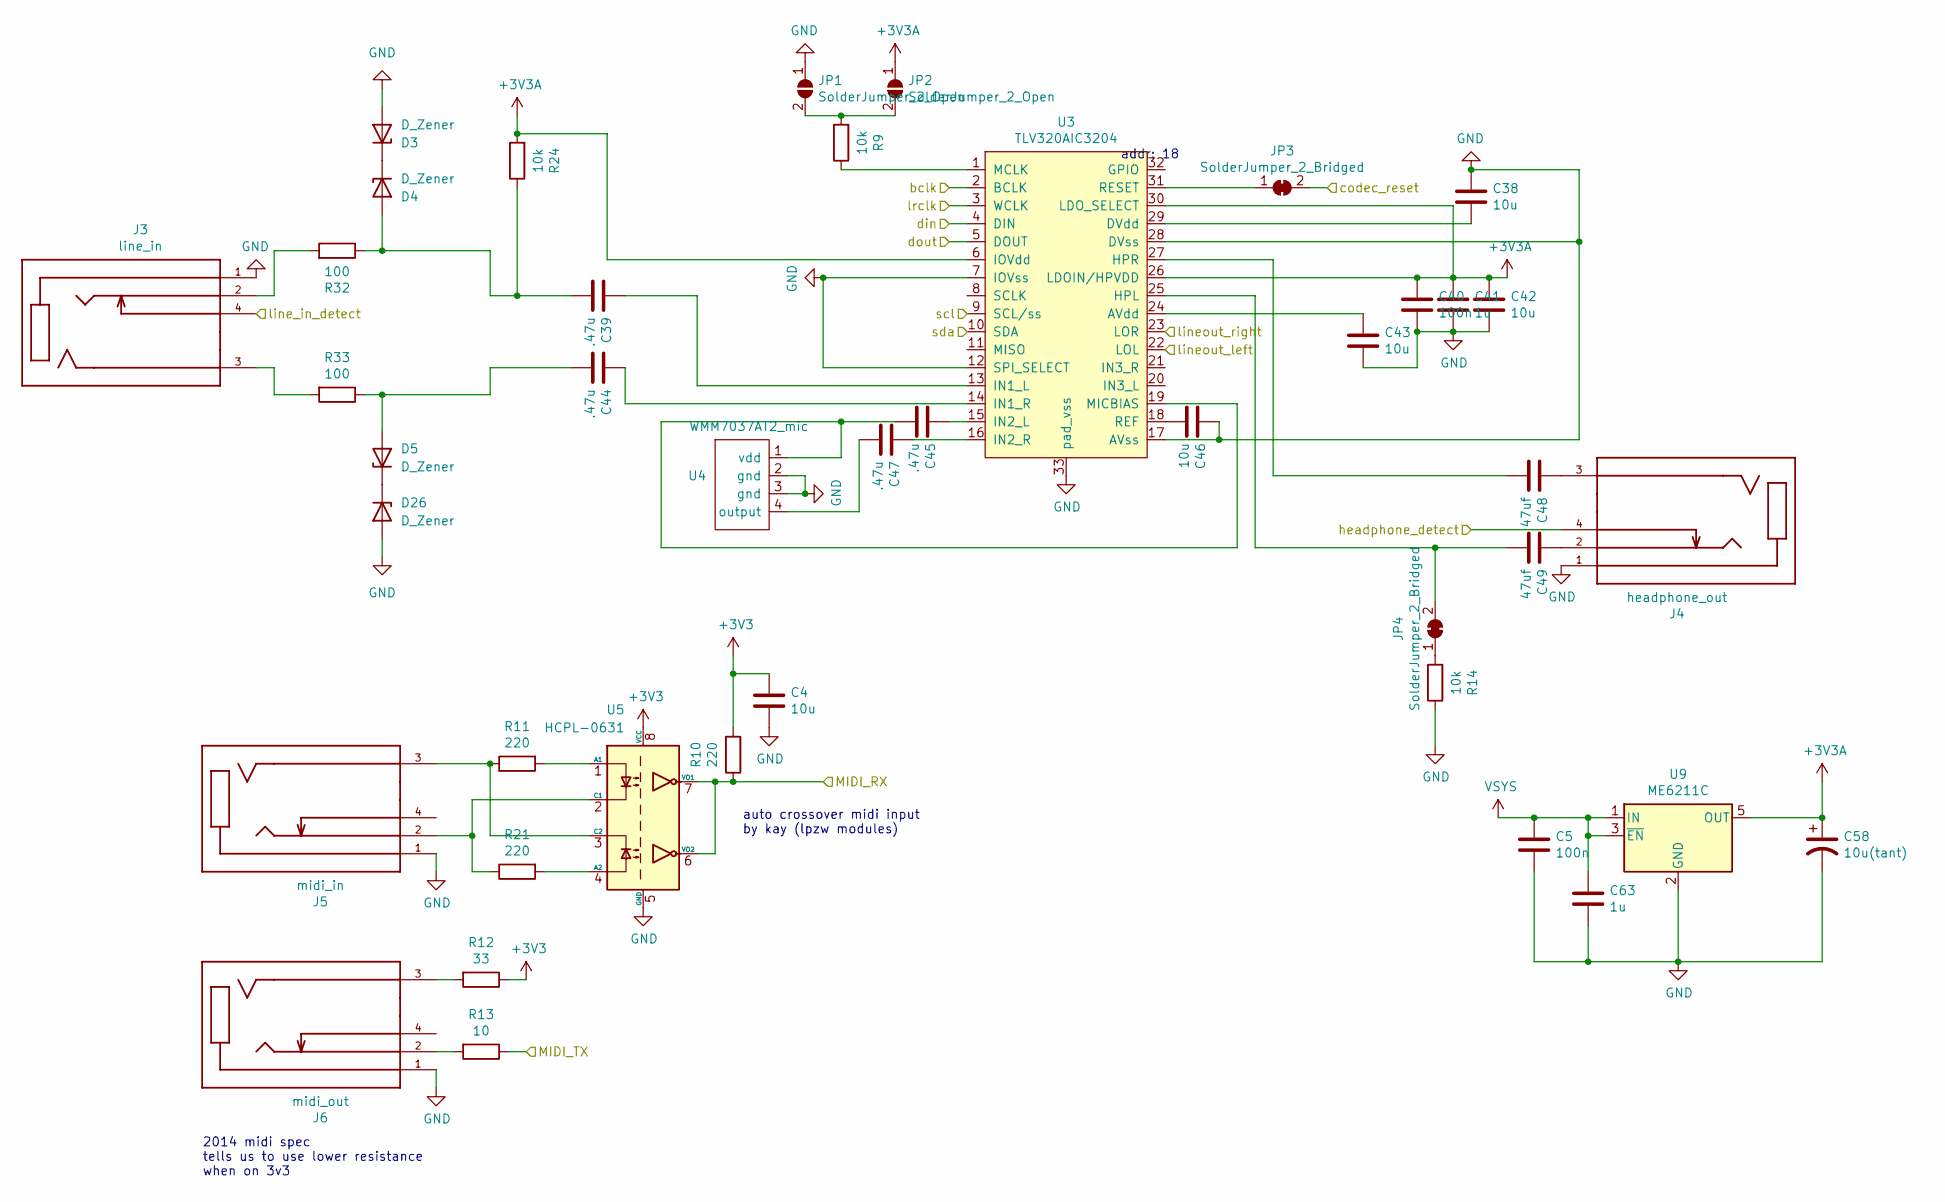
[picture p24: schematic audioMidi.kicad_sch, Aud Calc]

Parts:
C4, C38, C42, C43, C46: 10u; C_0402_1005Metric; LCSC C15525
C5, C40: 100n; C_0402_1005Metric; LCSC C307331
C39, C44, C45, C47: .47u; C_0603_nosilk; LCSC C1623
C41, C63: 1u; C_0402_1005Metric; LCSC C52923
C48, C49: 47uf; C_1206; LCSC C96123
C58: 10u(tant); CP_Tantalum_Case-A_EIA-3216-18_Reflow; LCSC C7171
D3, D4, D5, D26: D_Zener; D_SOD-323F; LCSC C52056
J3: line_in; HRO-PJ-327C-A; LCSC C145813
J4: headphone_out; HRO-PJ-327C-A; LCSC C145813
J5: midi_in; HRO-PJ-327C-A; LCSC C145813
J6: midi_out; HRO-PJ-327C-A; LCSC C145813
JP1, JP2: SolderJumper_2_Open; SolderJumper-2_P1.3mm_Open_RoundedPad1.0x1.5mm
JP3, JP4: SolderJumper_2_Bridged; SolderJumper-2_P1.3mm_Bridged_Pad1.0x1.5mm
R9, R14, R24: 10k; R_0402_1005Metric_nosilk; LCSC C25744
R10, R11, R21: 220; R_0402_1005Metric_nosilk; LCSC C25091
R12: 33; R_0402_1005Metric_nosilk; LCSC C25105
R13: 10; R_0402_1005Metric_nosilk; LCSC C25077
R32, R33: 100; R_0402_1005Metric; LCSC C25076
U3: TLV320AIC3204; QFN-32-1EP_5x5mm_Pitch0.5mm; LCSC C9925
U4: WMM7037AT2_mic; LGA-4 (3x3.8); LCSC C140705
U5: HCPL-0631; SOIC-8_3.9x4.9mm_P1.27mm; LCSC C43949
U9: ME6211C; SOT-23-5; LCSC C82942

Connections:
+3V3: C4.1, R10.2, R12.1, U5.8 (VCC); also elsewhere on the board
+3V3A: C40.1, C41.1, C42.1, C58.1, JP2.1 (A), R24.2, U3.6 (IOVdd), U3.26 (LDOIN/HPVDD), U3.30 (LDO_SELECT), U9.5 (OUT)
/AudioMidi/lineout_left: U3.22 (LOL)
/AudioMidi/lineout_right: U3.23 (LOR)
/MIDI_RX: R10.1, U5.6 (VO2), U5.7 (VO1); also elsewhere on the board
/MIDI_TX: R13.1; also elsewhere on the board
GND: C4.2, C5.2, C38.1, C40.2, C41.2, C42.2, C43.2, C46.1, C58.2, C63.2, D3.2 (A), D26.2 (A), J3.1 (SLEEVE), J4.1 (SLEEVE), J5.1 (SLEEVE), J6.1 (SLEEVE), JP1.1 (A), R14.1, U3.7 (IOVss), U3.12 (SPI_SELECT), U3.17 (AVss), U3.28 (DVss), U3.33 (pad_vss), U4.2 (gnd), U4.3 (gnd), U5.5 (GND), U9.2 (GND); also elsewhere on the board
unnamed: D3.1 (K), D4.1 (K)
unnamed: C39.2, D4.2 (A), R24.1, R32.1
unnamed: C44.2, D5.2 (A), R33.1
unnamed: D5.1 (K), D26.1 (K)
unnamed: J3.3 (RING), R33.2
unnamed: J3.2 (TIP_1), R32.2
unnamed: C48.1, J4.3 (RING)
unnamed: C49.1, J4.2 (TIP_1)
unnamed: J5.3 (RING), R11.1, U5.3 (C2)
unnamed: J5.2 (TIP_1), R21.1, U5.2 (C1)
unnamed: J6.3 (RING), R12.2
unnamed: J6.2 (TIP_1), R13.2
unnamed: JP1.2 (B), JP2.2 (B), R9.2
unnamed: JP3.1 (A), U3.31 (RESET)
unnamed: JP4.1 (A), R14.2
unnamed: C49.2, JP4.2 (B), U3.25 (HPL)
unnamed: C43.1, U3.24 (AVdd)
unnamed: C38.2, U3.29 (DVdd)
unnamed: C48.2, U3.27 (HPR)
unnamed: C39.1, U3.13 (IN1_L)
unnamed: C44.1, U3.14 (IN1_R)
unnamed: C45.1, U3.15 (IN2_L)
unnamed: C47.1, U3.16 (IN2_R)
unnamed: R9.1, U3.1 (MCLK)
unnamed: C45.2, U3.19 (MICBIAS), U4.1 (vdd)
unnamed: C46.2, U3.18 (REF)
unnamed: C47.2, U4.4 (output)
unnamed: R11.2, U5.1 (A1)
unnamed: R21.2, U5.4 (A2)
VSYS: C5.1, C63.1, U9.1 (IN), U9.3 (~EN); also elsewhere on the board
bck: U3.2 (BCLK); also elsewhere on the board
din: U3.4 (DIN); also elsewhere on the board
dout: U3.5 (DOUT); also elsewhere on the board
headphone_detect: J4.4 (TIP_SWITCH); also elsewhere on the board
line_in_detect: J3.4 (TIP_SWITCH); also elsewhere on the board
lrclk: U3.3 (WCLK); also elsewhere on the board
scl: U3.9 (SCL/ss); also elsewhere on the board
sda: U3.10 (SDA); also elsewhere on the board
subsystem_reset: JP3.2 (B); also elsewhere on the board

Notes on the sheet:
2014 midi spec tells us to use lower resistance when on 3v3
addr: 18
auto crossover midi input by kay (lpzw modules)

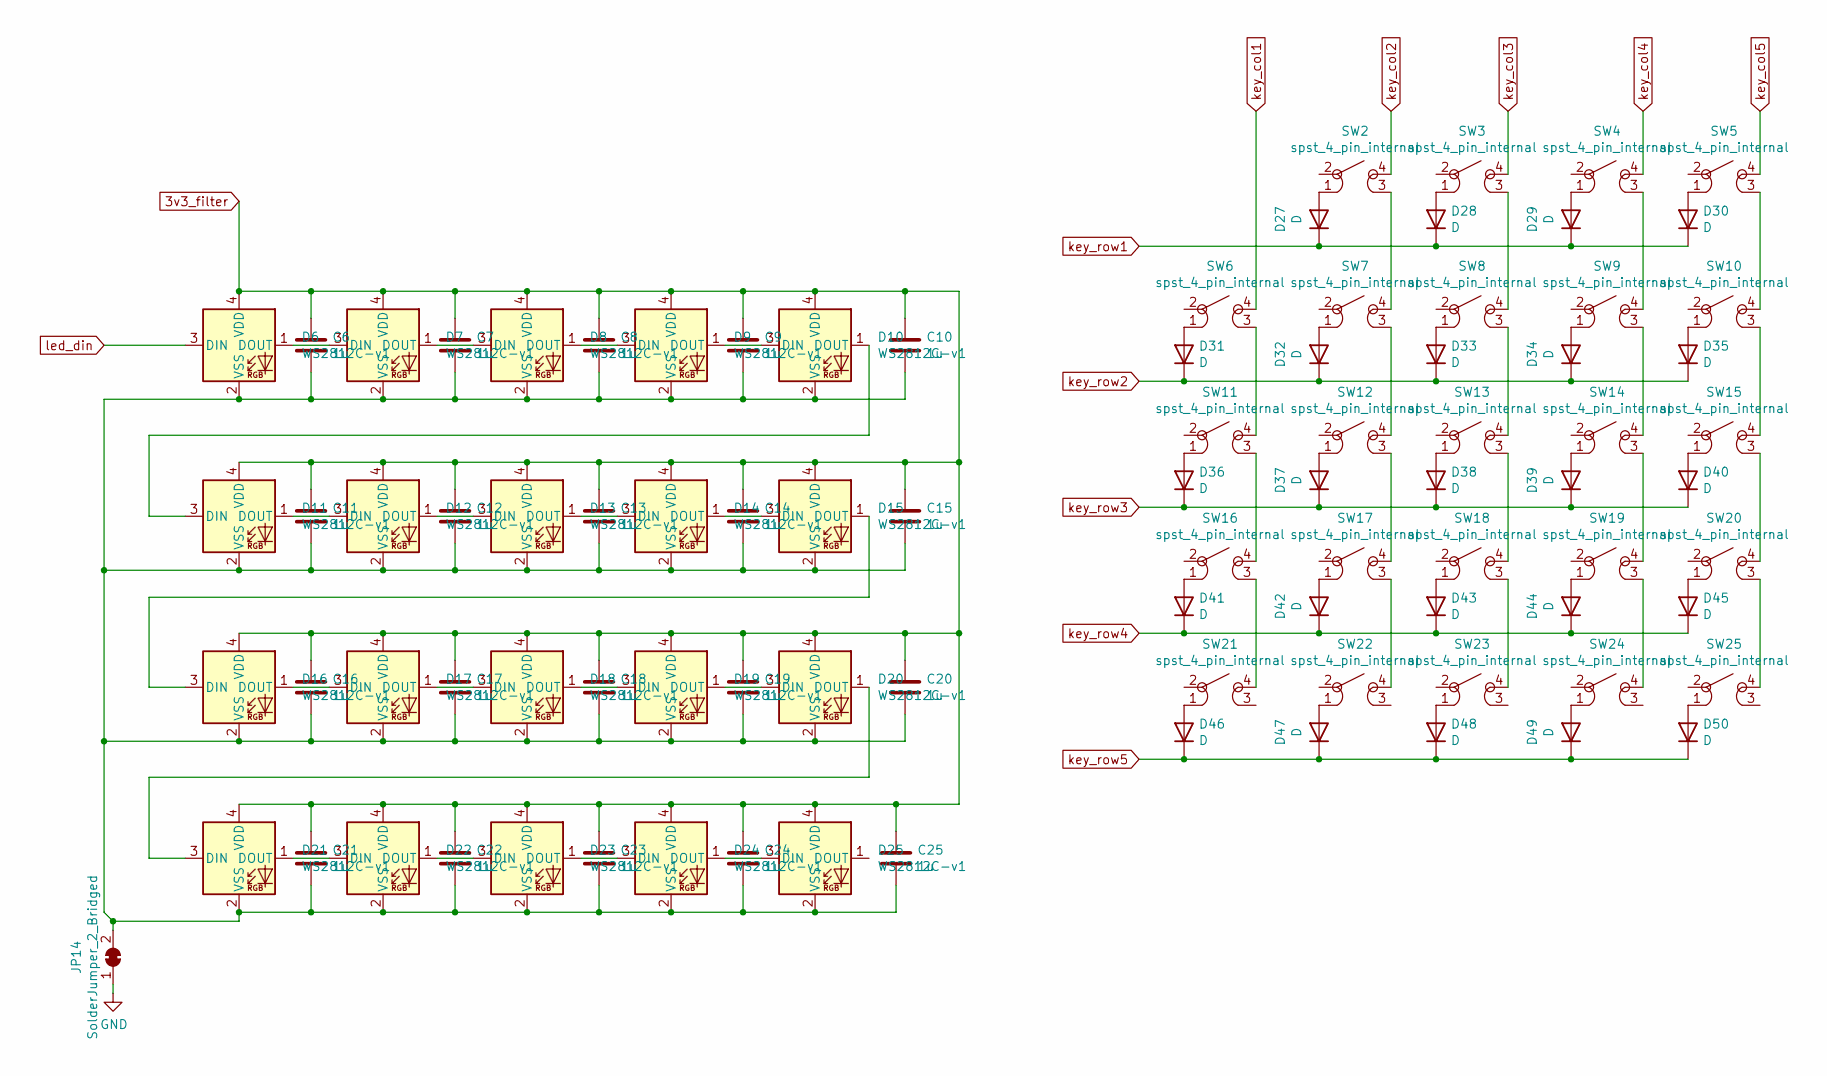
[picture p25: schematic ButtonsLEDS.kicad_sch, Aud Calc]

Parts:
C6, C7, C8, C9, C10, C11, C12, C13, C14, C15, C16, C17, C18, C19, C20, C21, C22, C23, C24, C25: 1u; C_0402_1005Metric; LCSC C52923
D6, D7, D8, D9, D10, D11, D12, D13, D14, D15, D16, D17, D18, D19, D20, D21, D22, D23, D24, D25: WS2812C-v1; ws2812b-2020-lightpipe; LCSC C2976072
D27, D28, D29, D30, D31, D32, D33, D34, D35, D36, D37, D38, D39, D40, D41, D42, D43, D44, D45, D46, D47, D48, D49, D50: D; D_SOD-323F_less_silk; LCSC C2128
JP14: SolderJumper_2_Bridged; SolderJumper-2_P1.3mm_Bridged_Pad1.0x1.5mm
SW2, SW3, SW4, SW5, SW6, SW7, SW8, SW9, SW10, SW11, SW12, SW13, SW14, SW15, SW16, SW17, SW18, SW19, SW20, SW21, SW22, SW23, SW24, SW25: spst_4_pin_internal; ts1187; LCSC C318884

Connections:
3v3_filter: C6.1, C7.1, C8.1, C9.1, C10.1, C11.1, C12.1, C13.1, C14.1, C15.1, C16.1, C17.1, C18.1, C19.1, C20.1, C21.1, C22.1, C23.1, C24.1, C25.1, D6.4 (VDD), D7.4 (VDD), D8.4 (VDD), D9.4 (VDD), D10.4 (VDD), D11.4 (VDD), D12.4 (VDD), D13.4 (VDD), D14.4 (VDD), D15.4 (VDD), D16.4 (VDD), D17.4 (VDD), D18.4 (VDD), D19.4 (VDD), D20.4 (VDD), D21.4 (VDD), D22.4 (VDD), D23.4 (VDD), D24.4 (VDD), D25.4 (VDD); also elsewhere on the board
GND: JP14.1 (A); also elsewhere on the board
unnamed: D6.1 (DOUT), D7.3 (DIN)
unnamed: D7.1 (DOUT), D8.3 (DIN)
unnamed: D8.1 (DOUT), D9.3 (DIN)
unnamed: D9.1 (DOUT), D10.3 (DIN)
unnamed: D10.1 (DOUT), D11.3 (DIN)
unnamed: C6.2, C7.2, C8.2, C9.2, C10.2, C11.2, C12.2, C13.2, C14.2, C15.2, C16.2, C17.2, C18.2, C19.2, C20.2, C21.2, C22.2, C23.2, C24.2, C25.2, D6.2 (VSS), D7.2 (VSS), D8.2 (VSS), D9.2 (VSS), D10.2 (VSS), D11.2 (VSS), D12.2 (VSS), D13.2 (VSS), D14.2 (VSS), D15.2 (VSS), D16.2 (VSS), D17.2 (VSS), D18.2 (VSS), D19.2 (VSS), D20.2 (VSS), D21.2 (VSS), D22.2 (VSS), D23.2 (VSS), D24.2 (VSS), D25.2 (VSS), JP14.2 (B)
unnamed: D11.1 (DOUT), D12.3 (DIN)
unnamed: D12.1 (DOUT), D13.3 (DIN)
unnamed: D13.1 (DOUT), D14.3 (DIN)
unnamed: D14.1 (DOUT), D15.3 (DIN)
unnamed: D15.1 (DOUT), D16.3 (DIN)
unnamed: D16.1 (DOUT), D17.3 (DIN)
unnamed: D17.1 (DOUT), D18.3 (DIN)
unnamed: D18.1 (DOUT), D19.3 (DIN)
unnamed: D19.1 (DOUT), D20.3 (DIN)
unnamed: D20.1 (DOUT), D21.3 (DIN)
unnamed: D21.1 (DOUT), D22.3 (DIN)
unnamed: D22.1 (DOUT), D23.3 (DIN)
unnamed: D23.1 (DOUT), D24.3 (DIN)
unnamed: D24.1 (DOUT), D25.3 (DIN)
unnamed: D27.2 (A), SW2.1
unnamed: D28.2 (A), SW3.1
unnamed: D29.2 (A), SW4.1
unnamed: D30.2 (A), SW5.1
unnamed: D31.2 (A), SW6.1
unnamed: D32.2 (A), SW7.1
unnamed: D33.2 (A), SW8.1
unnamed: D34.2 (A), SW9.1
unnamed: D35.2 (A), SW10.1
unnamed: D36.2 (A), SW11.1
unnamed: D37.2 (A), SW12.1
unnamed: D38.2 (A), SW13.1
unnamed: D39.2 (A), SW14.1
unnamed: D40.2 (A), SW15.1
unnamed: D41.2 (A), SW16.1
unnamed: D42.2 (A), SW17.1
unnamed: D43.2 (A), SW18.1
unnamed: D44.2 (A), SW19.1
unnamed: D45.2 (A), SW20.1
unnamed: D46.2 (A), SW21.1
unnamed: D47.2 (A), SW22.1
unnamed: D48.2 (A), SW23.1
unnamed: D49.2 (A), SW24.1
unnamed: D50.2 (A), SW25.1
unnamed: SW2.3, SW7.4
unnamed: SW3.3, SW8.4
unnamed: SW4.3, SW9.4
unnamed: SW10.3, SW15.4
unnamed: SW5.3, SW10.4
unnamed: SW11.3, SW16.4
unnamed: SW6.3, SW11.4
unnamed: SW12.3, SW17.4
unnamed: SW7.3, SW12.4
unnamed: SW13.3, SW18.4
unnamed: SW8.3, SW13.4
unnamed: SW14.3, SW19.4
unnamed: SW9.3, SW14.4
unnamed: SW15.3, SW20.4
unnamed: SW16.3, SW21.4
unnamed: SW17.3, SW22.4
unnamed: SW18.3, SW23.4
unnamed: SW19.3, SW24.4
unnamed: SW20.3, SW25.4
key_col1: SW6.4; also elsewhere on the board
key_col2: SW2.4; also elsewhere on the board
key_col3: SW3.4; also elsewhere on the board
key_col4: SW4.4; also elsewhere on the board
key_col5: SW5.4; also elsewhere on the board
key_row1: D27.1 (K), D28.1 (K), D29.1 (K), D30.1 (K); also elsewhere on the board
key_row2: D31.1 (K), D32.1 (K), D33.1 (K), D34.1 (K), D35.1 (K); also elsewhere on the board
key_row3: D36.1 (K), D37.1 (K), D38.1 (K), D39.1 (K), D40.1 (K); also elsewhere on the board
key_row4: D41.1 (K), D42.1 (K), D43.1 (K), D44.1 (K), D45.1 (K); also elsewhere on the board
key_row5: D46.1 (K), D47.1 (K), D48.1 (K), D49.1 (K), D50.1 (K); also elsewhere on the board
led_din: D6.3 (DIN); also elsewhere on the board

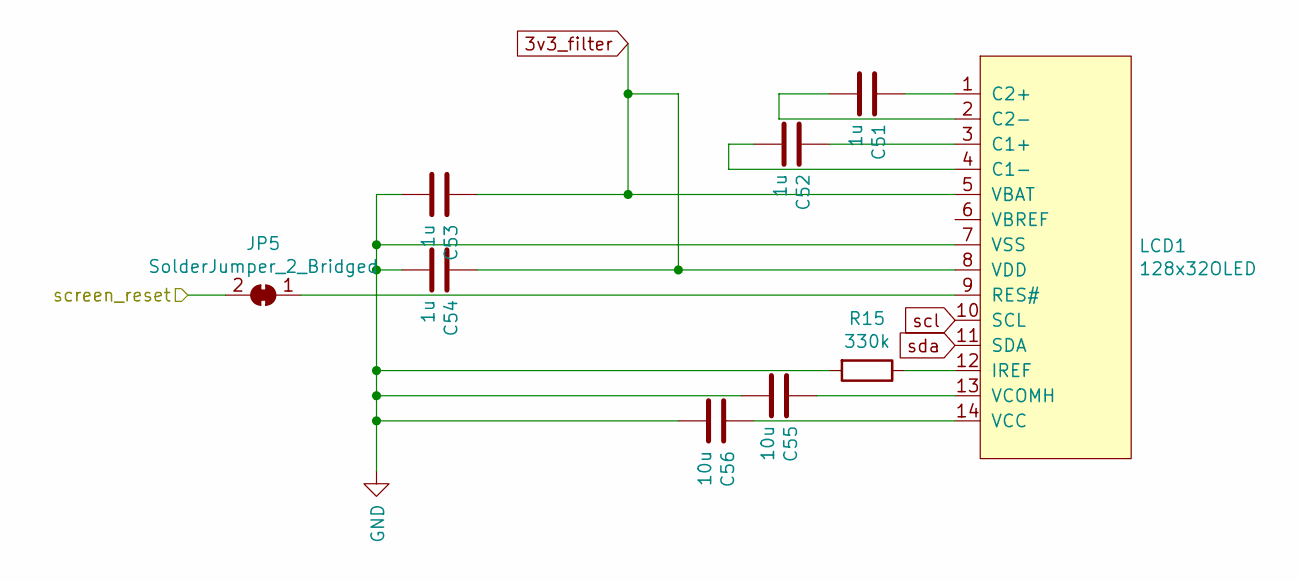
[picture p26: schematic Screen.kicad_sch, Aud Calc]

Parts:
C51, C52, C53, C54: 1u; C_0402_1005Metric; LCSC C52923
C55, C56: 10u; C_0402_1005Metric; LCSC C15525
JP5: SolderJumper_2_Bridged; SolderJumper-2_P1.3mm_Bridged_Pad1.0x1.5mm
LCD1: 128x32OLED; oled_ssd1306_14pin_91
R15: 330k; R_0402_1005Metric_nosilk; LCSC C25778

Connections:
3v3_filter: C53.1, C54.1, LCD1.5 (VBAT), LCD1.8 (VDD); also elsewhere on the board
GND: C53.2, C54.2, C55.2, C56.2, LCD1.7 (VSS), R15.2; also elsewhere on the board
unnamed: JP5.1 (A), LCD1.9 (RES#)
unnamed: C52.1, LCD1.3 (C1+)
unnamed: C52.2, LCD1.4 (C1-)
unnamed: C51.1, LCD1.1 (C2+)
unnamed: C51.2, LCD1.2 (C2-)
unnamed: LCD1.12 (IREF), R15.1
unnamed: C56.1, LCD1.14 (VCC)
unnamed: C55.1, LCD1.13 (VCOMH)
scl: LCD1.10 (SCL); also elsewhere on the board
sda: LCD1.11 (SDA); also elsewhere on the board
subsystem_reset: JP5.2 (B); also elsewhere on the board

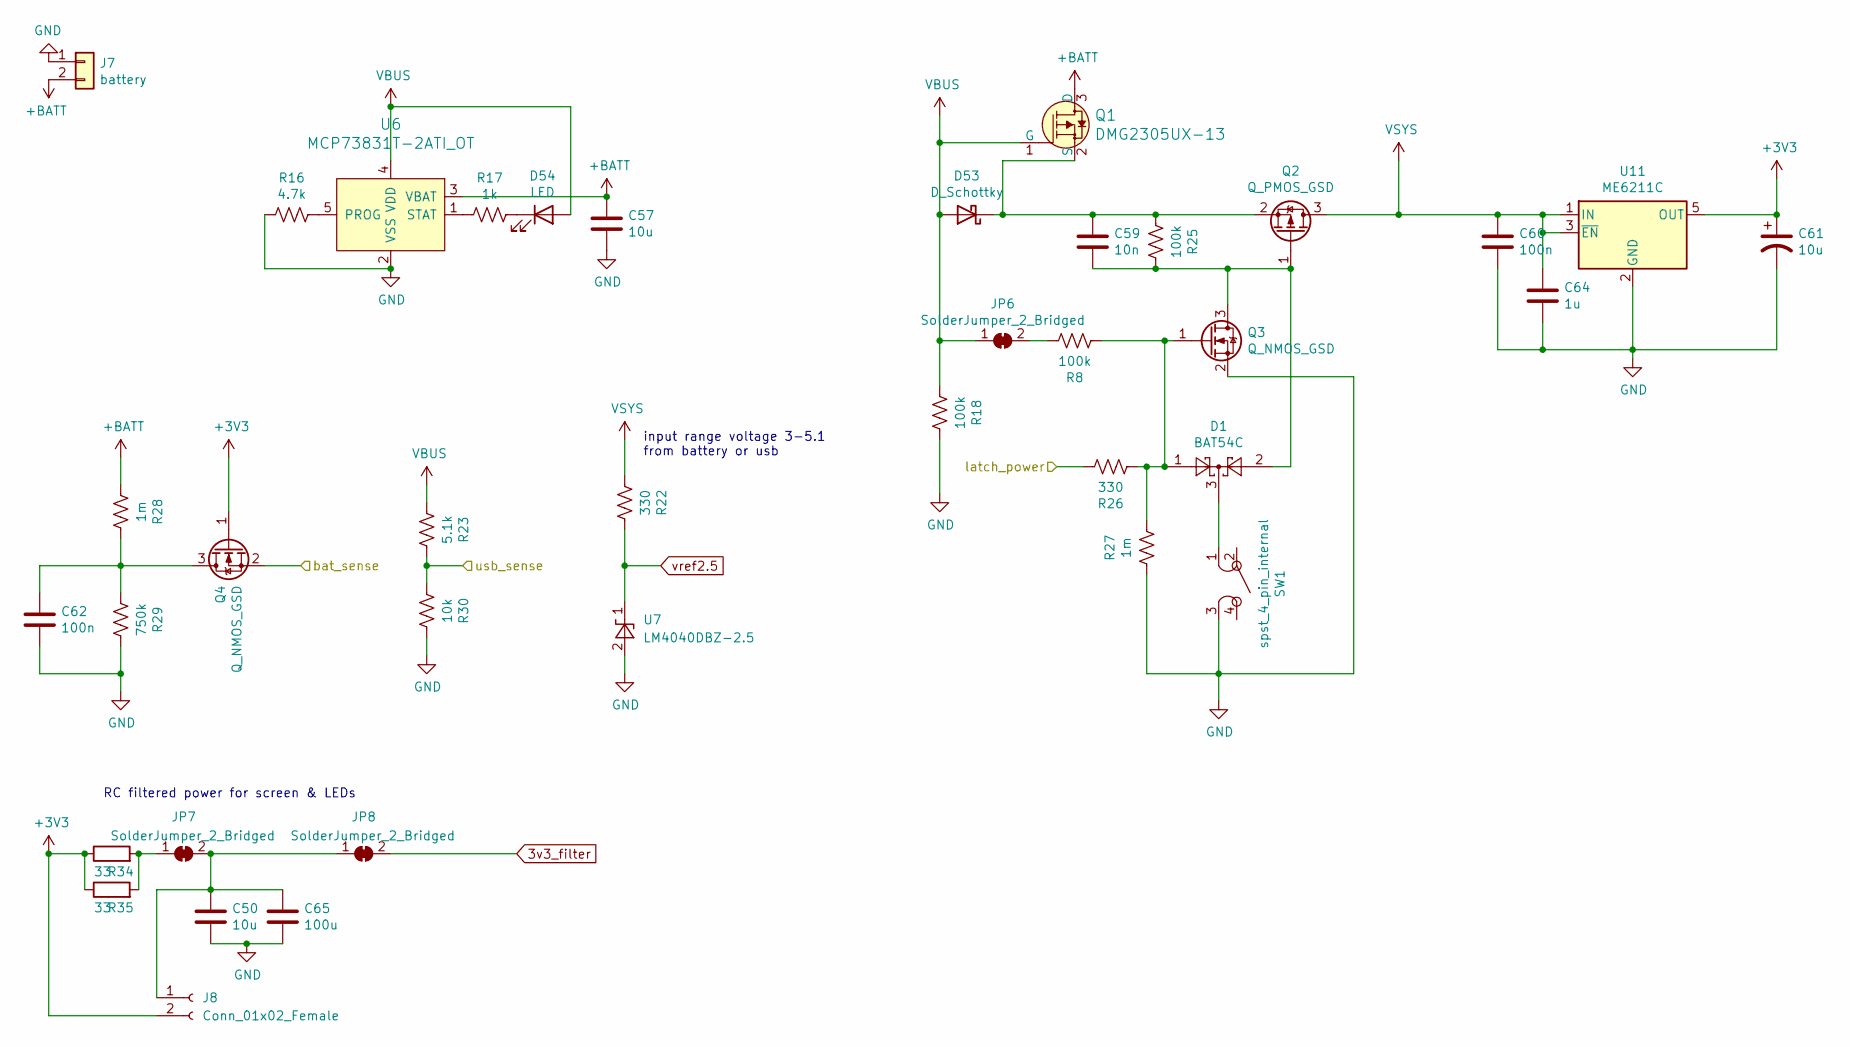
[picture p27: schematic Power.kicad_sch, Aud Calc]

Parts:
C50, C57, C61: 10u; C_0402_1005Metric; LCSC C15525
C59: 10n; C_0402_1005Metric; LCSC C15195
C60, C62: 100n; C_0402_1005Metric; LCSC C307331
C64: 1u; C_0402_1005Metric; LCSC C52923
C65: 100u; CP_EIA-3528-21_Kemet-B; LCSC C16133
D1: BAT54C; SOT-23; LCSC C37704
D53: D_Schottky; D_SMA; LCSC C14996
D54: LED; LED_0603; LCSC C2286
J7: battery; JST_PH_S2B-PH-SM4-TB_02x2.00mm_Angled; LCSC C3029440
J8: Conn_01x02_Female; PinHeader_1x02_P2.54mm_Vertical
JP6, JP7, JP8: SolderJumper_2_Bridged; SolderJumper-2_P1.3mm_Bridged_Pad1.0x1.5mm
Q1: DMG2305UX-13; SOT-23-3; LCSC C144153
Q2: Q_PMOS_GSD; SOT-23; LCSC C15127
Q3, Q4: Q_NMOS_GSD; SOT-23; LCSC C79015
R8, R18, R25: 100k; R_0402_1005Metric_nosilk; LCSC C25741
R16: 4.7k; R_0402_1005Metric_nosilk; LCSC C25900
R17: 1k; R_0402_1005Metric_nosilk; LCSC C11702
R22, R26: 330; R_0402_1005Metric_nosilk; LCSC C25104
R23: 5.1k; R_0402_1005Metric_nosilk; LCSC C25905
R27, R28: 1m; R_0402_1005Metric_nosilk; LCSC C26083
R29: 750k; C_0603_nosilk; LCSC C23240
R30: 10k; R_0402_1005Metric_nosilk; LCSC C25744
R34, R35: 33; R_0402_1005Metric_nosilk; LCSC C25105
SW1: spst_4_pin_internal; ts1187; LCSC C318884
U6: MCP73831T-2ATI_OT; SOT-23-5; LCSC C14879
U7: LM4040DBZ-2.5; SOT-23; LCSC C460607
U11: ME6211C; SOT-23-5; LCSC C82942

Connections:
3v3_filter: JP8.2 (B); also elsewhere on the board
+3V3: C61.1, J8.2, Q4.1 (G), R34.1, R35.1, U11.5 (OUT); also elsewhere on the board
+BATT: C57.1, J7.2, Q1.3 (D), R28.2, U6.3 (VBAT)
GND: C50.2, C57.2, C60.2, C61.2, C62.2, C64.2, C65.2, J7.1, Q3.2 (S), R16.2, R18.1, R27.2, R29.1, R30.1, SW1.3, U6.2 (VSS), U7.2 (A), U11.2 (GND); also elsewhere on the board
unnamed: D1.3, SW1.1
unnamed: C59.1, D53.1 (K), Q1.2 (S), Q2.2 (S), R25.2
unnamed: D54.1 (K), R17.1
unnamed: C50.1, C65.1, J8.1, JP7.2 (B), JP8.1 (A)
unnamed: JP6.2 (B), R8.1
unnamed: JP7.1 (A), R34.2, R35.2
unnamed: C59.2, D1.2, Q2.1 (G), Q3.3 (D), R25.1
unnamed: D1.1, Q3.1 (G), R8.2, R26.2, R27.1
unnamed: C62.1, Q4.3 (D), R28.1, R29.2
unnamed: R16.1, U6.5 (PROG)
unnamed: R17.2, U6.1 (STAT)
VBUS: D53.2 (A), D54.2 (A), JP6.1 (A), Q1.1 (G), R18.2, R23.2, U6.4 (VDD); also elsewhere on the board
VSYS: C60.1, C64.1, Q2.3 (D), R22.2, U11.1 (IN), U11.3 (~EN); also elsewhere on the board
bat_sense: Q4.2 (S); also elsewhere on the board
latch_power: R26.1; also elsewhere on the board
usb_sense: R23.1, R30.2; also elsewhere on the board
vref2.5: R22.1, U7.1 (K); also elsewhere on the board

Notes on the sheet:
RC filtered power for screen & LEDs
input range voltage 3-5.1 from battery or usb

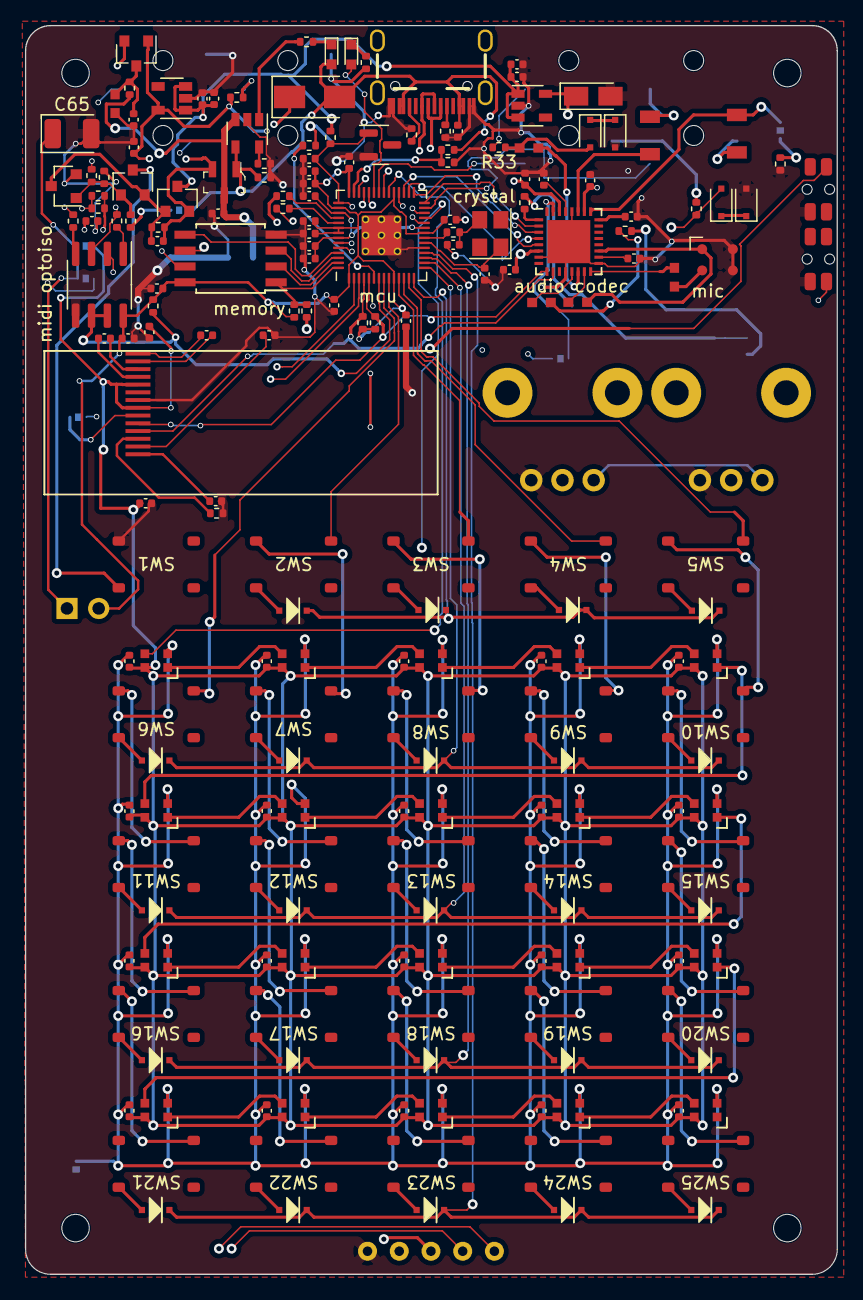
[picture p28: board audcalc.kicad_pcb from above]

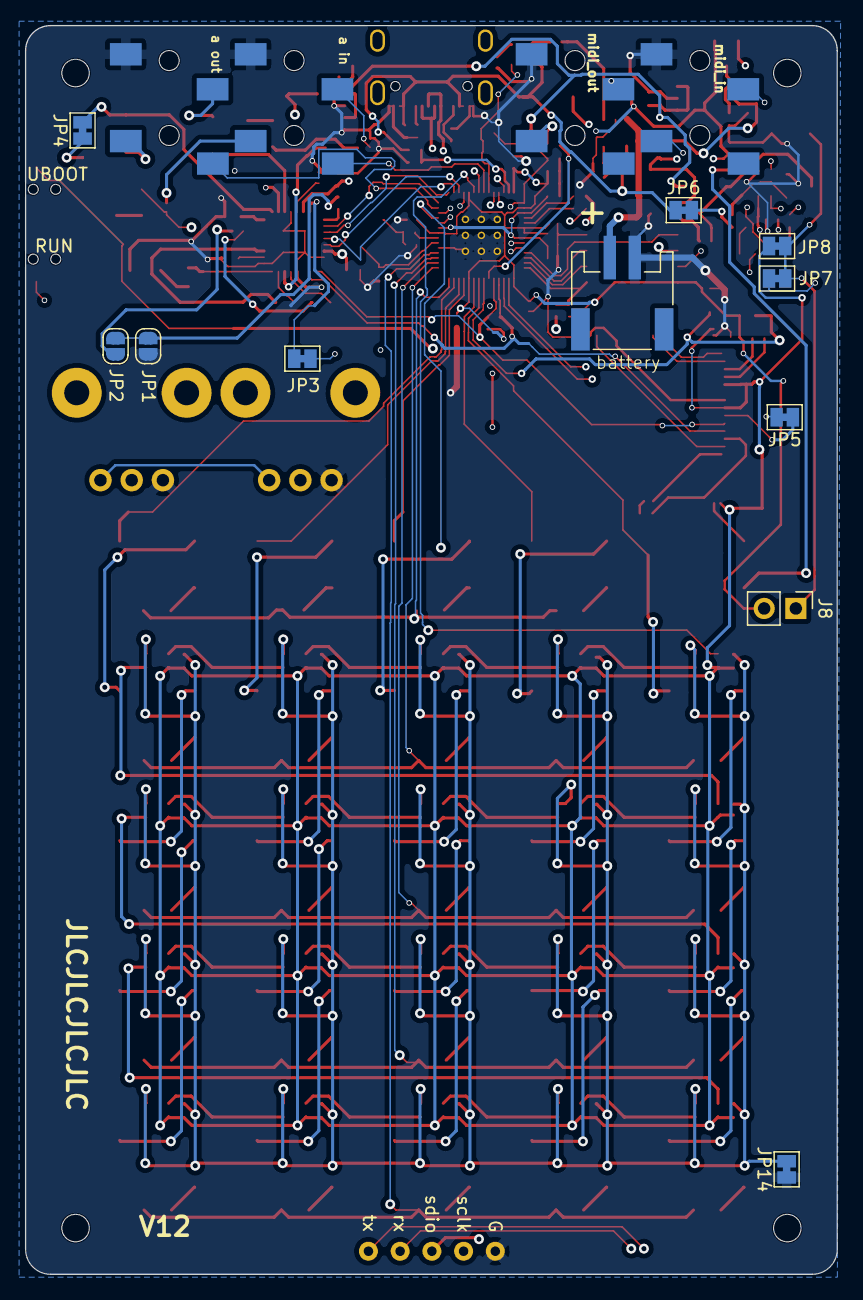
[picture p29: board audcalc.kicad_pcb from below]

Board: 4 copper layers, 65.0 x 100.0 mm, 218 parts (16 on the bottom side), 170 nets.

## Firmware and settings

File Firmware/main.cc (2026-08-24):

#include <stdio.h>
#include "pico/stdlib.h"
// #include "pico/sleep.h"
#include "hardware/i2c.h"
#include "hardware/dma.h"
#include "hardware/irq.h"
#include "hardware/pio.h"
#include "hardware/adc.h"
#include "hardware/flash.h"
#include "pico/multicore.h"
#include "pico/util/queue.h"
#include "hardware/structs/scb.h"
// #include "hardware/rosc.h"

#include <math.h>

#include "hardware/clocks.h"
#include "hardware/structs/clocks.h"
#include "input_output_copy_i2s.pio.h"
#include "ws2812.pio.h"
#include "tlv320driver.h"

extern "C" {
#include "ssd1306.h"
//#include "usb_audio.h"
}
#include "m6x118pt7b.h"

#include "GrooveBox.h"
#include "audio/macro_oscillator.h"

#include "filesystem.h"
#include "ws2812.h"
#include "hardware.h"
#include <pb_encode.h>
#include <pb_decode.h>
#include "ParamLockPoolInternal.pb.h"
#include "USBSerialDevice.h"
#include "diagnostics.h"
#include "multicore_support.h"
#include "GlobalDefines.h"
#include "bsp/board.h"
#include "Midi.h"

using namespace braids;


#define TLV_I2C_ADDR            0x18
#define TLV_REG_PAGESELECT	    0
#define TLV_REG_LDOCONTROL	    2
#define TLV_REG_RESET   	    1
#define TLV_REG_CLK_MULTIPLEX   	0x04

#define USING_DEMO_BOARD 0
// AudCalc board defines
#if USING_DEMO_BOARD
    #define I2S_DATA_PIN 26
    #define I2S_BCLK_PIN 27
#else
    #define I2S_DATA_PIN 19
    #define I2S_BCLK_PIN 17
#endif
// demo board defines

void on_usb_microphone_tx_ready();

static float clip(float value)
{
    value = value < -1.0f ? -1.0f : value;
    value = value > +1.0f ? +1.0f : value;
    return value;
}

int dma_chan_input;
int dma_chan_output;
uint sm;

bool audioInReady = false;
bool audioOutReady = false;
uint32_t capture_buf[SAMPLES_PER_BLOCK*BLOCKS_PER_SEND*2];
uint32_t output_buf[SAMPLES_PER_BLOCK*BLOCKS_PER_SEND*2];

int outBufOffset = 0;
int inBufOffset = 0;
int audioGenOffset = 0;
GrooveBox gbox;
USBSerialDevice usbSerialDevice;
auto_init_mutex(audioProcessMutex);

int triCount = 0;
int note = 60;


/*
* double buffered audio - if the signal that the next frame of audio hasn't completed sending,
*/ 

void __not_in_flash_func(dma_input_handler)() {
    if (dma_hw->ints0 & (1u<<dma_chan_input)) {
        dma_hw->ints0 = (1u << dma_chan_input);
        dma_channel_set_write_addr(dma_chan_input, capture_buf+(inBufOffset)*SAMPLES_PER_SEND, true);
        uint32_t x;
        if(mutex_try_enter(&audioProcessMutex, &x))
        {
            inBufOffset = (inBufOffset+1)%2;
            audioInReady = true;
            mutex_exit(&audioProcessMutex);
        }
    }
}

void __not_in_flash_func(dma_output_handler)() {
    if (dma_hw->ints0 & (1u<<dma_chan_output)) {
        dma_hw->ints0 = 1u << dma_chan_output;
        dma_channel_set_read_addr(dma_chan_output, output_buf+(outBufOffset)*SAMPLES_PER_SEND, true);
        uint32_t x;
        if(mutex_try_enter(&audioProcessMutex, &x))
        {
            outBufOffset = (outBufOffset+1)%2;
            audioOutReady = true;
            mutex_exit(&audioProcessMutex);
        }
    }
}

int flashReadPos = 0;

static inline void put_pixel(uint32_t pixel_grb) {
    pio_sm_put_blocking(pio0, 0, pixel_grb << 8u);
}

bool needsScreenupdate;
bool repeating_timer_callback(struct repeating_timer *t) {
    needsScreenupdate = true;
    return true;
}

bool usb_timer_callback(struct repeating_timer *t) {
    //usbaudio_update();
    return true;
}

bool screen_flip_ready = false;
int drawY = 0;
void __not_in_flash_func(draw_screen)()
{
    // this needs to be called here, because the multicore launch relies on
    // the fifo being functional
    sleep_ms(20);
    multicore_lockout_victim_init();
    while(true)
    {
        // drain any live-sampling record blocks to flash off the audio core
        gbox.DrainRecording();
        queue_entry_t entry;
        if(queue_try_remove(&signal_queue, &entry))
        {
            if(entry.renderInstrument >= 0)
            {
                gbox.instruments[entry.renderInstrument].Render(entry.sync_buffer, entry.workBuffer, 64);
                queue_entry_complete_t result;
                result.renderInstrumentComplete = true;
                queue_add_blocking(&renderCompleteQueue, &result);
            }
        }
    }
}


void configure_audio_driver()
{
    /**/
    PIO pio = pio1;
    uint offset = pio_add_program(pio, &input_output_copy_i2s_program);
    printf("loaded program at offset: %i\n", offset);
    sm = pio_claim_unused_sm(pio, true);
    printf("claimed sm: %i\n", sm); //I2S_DATA_PIN
    int sample_freq = AUDIO_SAMPLE_RATE;
    printf("setting pio freq %d\n", (int) sample_freq);
    uint32_t system_clock_frequency = clock_get_hz(clk_sys);
    assert(system_clock_frequency < 0x40000000);

    uint32_t divider = system_clock_frequency*2 / sample_freq; // avoid arithmetic overflow
    // uint32_t divider = system_clock_frequency/(sample_freq*3*32);
    printf("System clock at %u, I2S clock divider 0x%x/256\n", (uint) system_clock_frequency, (uint)divider);
    assert(divider < 0x1000000);
    input_output_copy_i2s_program_init(pio, sm, offset, I2S_DATA_PIN, I2S_DATA_PIN+1, I2S_BCLK_PIN);
    pio_sm_set_enabled(pio, sm, true);
    pio_sm_set_clkdiv_int_frac(pio, sm, divider >> 8u, divider & 0xffu);

    // just use a dma to pull the data out. Whee!
    dma_chan_input = dma_claim_unused_channel(true);
    dma_channel_config c = dma_channel_get_default_config(dma_chan_input);
    channel_config_set_read_increment(&c,false);
    // increment on write
    channel_config_set_write_increment(&c,true);
    channel_config_set_dreq(&c,pio_get_dreq(pio,sm,false));
    channel_config_set_transfer_data_size(&c, DMA_SIZE_32);

    dma_channel_configure(
        dma_chan_input,
        &c,
        capture_buf, // Destination pointer
        &pio->rxf[sm], // Source pointer
        SAMPLES_PER_SEND, // Number of transfers
        true// Start immediately
    );
    // Tell the DMA to raise IRQ line 0 when the channel finishes a block
    dma_channel_set_irq0_enabled(dma_chan_input, true);

    // Configure the processor to run dma_handler() when DMA IRQ 0 is asserted
    irq_add_shared_handler(DMA_IRQ_0, dma_input_handler, PICO_SHARED_IRQ_HANDLER_DEFAULT_ORDER_PRIORITY-1);
    irq_set_enabled(DMA_IRQ_0, true);
    // need another dma channel for output
    dma_chan_output = dma_claim_unused_channel(true);
    dma_channel_config cc = dma_channel_get_default_config(dma_chan_output);
    // increment on read, but not on write
    channel_config_set_read_increment(&cc,true);
    channel_config_set_write_increment(&cc,false);
    channel_config_set_dreq(&cc,pio_get_dreq(pio,sm,true));
    channel_config_set_transfer_data_size(&cc, DMA_SIZE_32);
    dma_channel_configure(
        dma_chan_output,
        &cc,
        &pio->txf[sm], // Destination pointer
        output_buf, // Source pointer
        SAMPLES_PER_SEND, // Number of transfers
        true// Start immediately
    );
    dma_channel_set_irq0_enabled(dma_chan_output, true);
    // Configure the processor to run dma_handler() when DMA IRQ 0 is asserted
    irq_add_shared_handler(DMA_IRQ_0, dma_output_handler, PICO_SHARED_IRQ_HANDLER_DEFAULT_ORDER_PRIORITY-2);
    irq_set_enabled(DMA_IRQ_0, true);
}

uint8_t adc1_prev;
uint8_t adc2_prev;

#define LINE_IN_DETECT 24
#define HEADPHONE_DETECT 16

int main(){
    stdio_init_all();
    board_init();
    tusb_init();

    hardware_init();
    // Diagnostics diag;
    // diag.flashQuickClear();
    {
        // if the user isn't holding the powerkey, 
        // or if holding power & esc then immediately shutdown
        if(!hardware_get_key_state(0,0) || hardware_get_key_state(3, 0))
        {
            hardware_shutdown();
        }
        if(hardware_get_key_state(4, 4) && hardware_get_key_state(0, 4))
        {
            Diagnostics diag;
            diag.run();
            // diag.flashQuickClear();
        }
        else if(hardware_get_key_state(4, 4))
        {
            hardware_reboot_usb();
        }
    }

    ws2812_init();
    uint32_t color[25];
    memset(color, 0, 25 * sizeof(uint32_t));
    ws2812_setColors(color+5);
    ws2812_trigger();

    
    queue_init(&signal_queue, sizeof(queue_entry_t), 3);
    queue_init(&complete_queue, sizeof(queue_entry_complete_t), 2);
    queue_init(&renderCompleteQueue, sizeof(queue_entry_complete_t), 2);
    queue_entry_complete_t result;
    result.renderInstrumentComplete = false;
    queue_add_blocking(&complete_queue, &result);
    multicore_launch_core1(draw_screen);
    struct repeating_timer timer;
    struct repeating_timer timer2;

    // requires some looping to get a good startup battery reading
    for(int i=0;i<100;i++)
    {
        sleep_ms(1);
        hardware_update_battery_level();
    }

    if(!hardware_has_usb_power() && hardware_get_battery_level_float() < 3.6f)
    {
        // display low battery, then shutdown
        add_repeating_timer_ms(-33, repeating_timer_callback, NULL, &timer);
        while(true)
        {
            tud_task(); // tinyusb device task
            midi_task(); // read and clear incoming midi
            if(needsScreenupdate)
            {
                gbox.LowBatteryDisplay  (GetDisplay());
                // hardware_has_usb_power(); // this call just turns on the green debug led currently
                ssd1306_show(GetDisplay());
                needsScreenupdate = false;
            }
        }
    }
    // core1 now writes flash during live sampling (GrooveBox::DrainRecording),
    // so core0 must be a lockout victim for that flash-program handshake to
    // complete. core1 already registered itself as a victim inside draw_screen
    // (after its 20ms startup sleep, so the FIFO launch handshake is done).
    multicore_lockout_victim_init();

    // if the user is holding down specific keys on powerup, then clear the full file system
    InitializeFilesystem(hardware_get_key_state(0,4) && hardware_get_key_state(3, 4), get_rand_32());

    //usbSerialDevice.Init();
    gbox.init(color);

    memset(output_buf, SAMPLES_PER_SEND*2, sizeof(uint32_t));
    memset(capture_buf, SAMPLES_PER_SEND*2, sizeof(uint32_t));

    configure_audio_driver();

    tlvDriverInit();

    int step = 0;
    uint32_t keyState = 0;
    uint32_t lastKeyState = 0;

    add_repeating_timer_ms(-33, repeating_timer_callback, NULL, &timer);

    adc_select_input(0);
    int16_t touchCounter = 0x7fff;
    int16_t headphoneCheck = 60;
    uint8_t brightnesscount = 0;
    int lostCount = 0;
    while(true)
    {
        tud_task(); // tinyusb device task
        midi_task(); // read and clear incoming midi
        if(audioOutReady && audioInReady)
        {
            mutex_enter_blocking(&audioProcessMutex); 
            for(int i=0;i<BLOCKS_PER_SEND;i++)
            {
                uint32_t *input = capture_buf+inBufOffset*SAMPLES_PER_SEND+SAMPLES_PER_BLOCK*i;
                uint32_t *output = output_buf+outBufOffset*SAMPLES_PER_SEND+SAMPLES_PER_BLOCK*i;
                gbox.Render((int16_t*)(output), (int16_t*)(input), SAMPLES_PER_BLOCK);
            }
            audioInReady = false;
            audioOutReady = false;
            mutex_exit(&audioProcessMutex);
        }
        else
        {
            hardware_get_all_key_state(&keyState);
            
            // act on keychanges
            for (size_t i = 0; i < 25; i++)
            {
                uint32_t s = keyState & (1ul<<i);
                if((keyState & (1ul<<i)) != (lastKeyState & (1ul<<i)))
                {
                    gbox.OnKeyUpdate(i, s>0); 
                }
            }
            lastKeyState = keyState;
            if(needsScreenupdate)
            {
                adc_select_input(1);
                uint16_t adc_val = adc_read();
                adc_select_input(0);
                gbox.OnAdcUpdate(adc_val, adc_read());
                hardware_update_battery_level();
                gbox.UpdateDisplay(GetDisplay());
                ssd1306_show(GetDisplay());
                ws2812_setColors(color+5);
                needsScreenupdate = false;
                ws2812_trigger();
            }
        }
    }
    return 0;
}

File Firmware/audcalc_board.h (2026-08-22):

#ifndef _BOARDS_AUDCALC_BOARD_H
#define _BOARDS_AUDCALC_BOARD_H

// --- UART ---
#ifndef PICO_DEFAULT_UART
#define PICO_DEFAULT_UART 0
#endif
#ifndef PICO_DEFAULT_UART_TX_PIN
#define PICO_DEFAULT_UART_TX_PIN 0
#endif
#ifndef PICO_DEFAULT_UART_RX_PIN
#define PICO_DEFAULT_UART_RX_PIN 1
#endif

// --- LED ---
#ifndef PICO_DEFAULT_LED_PIN
#define PICO_DEFAULT_LED_PIN 25
#endif
// no PICO_DEFAULT_WS2812_PIN

// --- I2C ---
#ifndef PICO_DEFAULT_I2C
#define PICO_DEFAULT_I2C 0
#endif
#ifndef PICO_DEFAULT_I2C_SDA_PIN
#define PICO_DEFAULT_I2C_SDA_PIN 4
#endif
#ifndef PICO_DEFAULT_I2C_SCL_PIN
#define PICO_DEFAULT_I2C_SCL_PIN 5
#endif

// --- SPI ---
#ifndef PICO_DEFAULT_SPI
#define PICO_DEFAULT_SPI 0
#endif
#ifndef PICO_DEFAULT_SPI_SCK_PIN
#define PICO_DEFAULT_SPI_SCK_PIN 18
#endif
#ifndef PICO_DEFAULT_SPI_TX_PIN
#define PICO_DEFAULT_SPI_TX_PIN 19
#endif
#ifndef PICO_DEFAULT_SPI_RX_PIN
#define PICO_DEFAULT_SPI_RX_PIN 16
#endif
#ifndef PICO_DEFAULT_SPI_CSN_PIN
#define PICO_DEFAULT_SPI_CSN_PIN 17
#endif

// --- FLASH ---

#define PICO_BOOT_STAGE2_CHOOSE_W25Q080 1

#ifndef PICO_FLASH_SPI_CLKDIV
#define PICO_FLASH_SPI_CLKDIV 2
#endif

#ifndef PICO_FLASH_SIZE_BYTES
#define PICO_FLASH_SIZE_BYTES (16 * 1024 * 1024)
#endif

// Drive high to force power supply into PWM mode (lower ripple on 3V3 at light loads)
#define PICO_SMPS_MODE_PIN 23

#ifndef PICO_RP2040_B0_SUPPORTED
#define PICO_RP2040_B0_SUPPORTED 1
#endif

#endif

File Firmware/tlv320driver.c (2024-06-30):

#include "tlv320driver.h"
#include "i2c_dma.h"

#define I2C_PORT i2c1
#define I2C_SDA 2
#define I2C_SCL 3
#define TLV_RESET_PIN 21
// #define TLV_DEBUG 1
#define TLV_I2C_ADDR            0x18
#define TLV_REG_PAGESELECT	    0
#define TLV_REG_LDOCONTROL	    2
#define TLV_REG_RESET   	    1
#define TLV_REG_CLK_MULTIPLEX   	0x04

uint8_t currentPage = -1;
bool writeRegister(uint8_t reg, uint8_t val)
{
    uint8_t data[2];
    data[0] = reg;
    data[1] = val;
	int attempt=0;
	while (1) {
        attempt++;
        
        int ret = i2c_write_blocking(I2C_PORT, TLV_I2C_ADDR, data, 2, false);
        if (ret == 2) {
            #ifdef TLV_DEBUG
            printf("TLV320 write ok, %d tries\n", attempt);
            #endif
            return true;
        }
        if (attempt >= 12) {
            #ifdef TLV_DEBUG
            printf("TLV320 write failed, %d tries\n", attempt);
            #endif
            return false;
        }
        //sleep_us(80);
    }
}
bool readRegister(uint8_t page, uint8_t reg, uint8_t *rxdata)
{
    if(currentPage != page)
    {
        if(!writeRegister(0, page))
        {
            //printf("failed to go to page %i\n", page);
            return false;
        }
        currentPage = page;
    }

	int attempt=0;
	while (1) {
		attempt++;        
        int ret = i2c_write_blocking(I2C_PORT, TLV_I2C_ADDR, &reg, 1, true);
		if (ret == 1) {
            int ret;
            attempt = 0;
            ret = i2c_read_blocking(I2C_PORT, TLV_I2C_ADDR, rxdata, 1, false);
            if(ret == 1)
            {
                return true;
            }
            else
            {
                return false;
            }
        }
        if (attempt >= 12) {
            //printf("TLV320 read failed, %d tries\n", attempt);
            return false;
        }
        //sleep_us(80);
    }
}
bool write(uint8_t page, uint8_t reg, uint8_t val)
{
    if(currentPage != page)
    {
        if(!writeRegister(0, page))
        {
            //printf("failed to go to page %i\n", page);
            return false;
        }
        currentPage = page;
    }
    return writeRegister(reg, val);
}

void tlvDriverInit()
{
        // reset
    write(0, 0x01, 0x01);

    // configure pll dividers
    // our bitclock runs at 32x(sample_freq)
    // so with 44100 we use the following values
    // pllp 1 pllr 3 pllj 20 plld 0 MADC 3 NADC 5 AOSR 128 MDAC 3 NDAC 5 DOSR 128
    // 44100*32*3*20.0

    // use bitclock for pll input, pll for clock input
    write(0, 0x04, 0x07);

    // pll p & r & powerup
    write(0, 0x05, (0x01<<7)|(0x01<<4)|0x03);
    // pll j
    write(0, 0x06, 0x14);


    // ndac &p powerup
    write(0, 0x0b, 0x80|0x05);
    // mdac & powerup
    write(0, 0x0c, 0x80|0x03); // original settings
    write(0, 0x0c, 0x80|0x02); // messing around

    // adc clocks should be driven by dac clocks, so no power necessary
    // but you still need to set them correctly
    write(0, 0x12, 0x05);
    write(0, 0x13, 0x03);
    write(0, 0x13, 0x02); // messing around - as above

    // dosr 64
    write(0, 0x0d, 0x00);
    write(0, 0x0e, 0x40);

    // adc osr 64
    write(0, 0x14, 0x40);
    // Select ADC PRB_R7
    write(0, 0x3d, 0x07);

    // bitclock offset
    // write(0, 0x1c, 0x2);
    // bitclock polarity flip
    // write(0, 0x1d, 0x08);
    // word length
    // processing block? default doesn't have the beep generator :(
    // printf("setup clocks\n");
    // sleep_ms(1000);
    // printf("one second to power\n");
    // sleep_ms(1000);
    // printf("power\n");
    // power enable
    // disable internal avdd prior to powering up internal LDO
    write(1, 0x01, 0x08);
    // enable analog power blocks

    // common mode voltage
    //
    // set ref to slow powerup
    write(1, 0x7b, 0x00);
    // HP softstepping settingsfor optimal pop performance at power up
    // Rpopusedis 6k withN = 6 and softstep= 20usec.Thisshouldworkwith47uFcoupling
    // capacitor.Can try N=5, 6 or 7 time constants as well.Trade-offdelay vs “pop” sound.
    write(1, 0x14, 0x25);
    // enable LDO
    write(1, 0x02, 0x01);

    // setup headphones to be powered by ldo
    // and set LDO input to 1.8-3.3
    write(1, 0x0a, 0x4B);

    // Set MicPGA startup delay to 3.1ms
    write(1, 0x47, 0x32);
    
    // micbias must always be on to avoid noise
    // write(1, 0x33, 0x68); // micbias enable, 2.5v
    // write(1, 0x33, 0x54); // micbias enable, 1.7v LDO in generation
    //write(1, 0x33, 0x50); // micbias enable, 1.7v avdd  generation
    // write(1, 0x33, 0x74); // micbias enable, powersupply
    
    driver_set_mic(false);
    
    // // analog bypass & dac routed to headphones
    // write(1, 0x0c, 0x0a);
    // write(1, 0x0d, 0x0a);

    // // dac & mixer to headphones
    // write(1, 0x0c, 0x0a);
    // write(1, 0x0d, 0x0a);
    
    // route dac only to headphones
    write(1, 0x0c, 0x08);
    write(1, 0x0d, 0x08);

    // dac and mixer to lineout
    write(1, 0x0e, 0x08);
    write(1, 0x0f, 0x08);
    
    // Set the ADC PTM Mode to PTM_R1
    write(1, 0x3d, 0x01);
    // Set the HPL gain to 0dB
    write(1, 0x10, 0x0); //0x1d maximum for sync output
    write(1, 0x11, 0x0);
    
    // set lineout gain to 0  db
    write(1, 0x12, 0x0);
    write(1, 0x13, 0x0);
    // set lineout gain to 20 db
    write(1, 0x12, 10);
    write(1, 0x13, 10);

    // power up headphones & mixer amp
    write(1, 0x09, 0x33);

    // power up headphones, lineout & mixer amp
    write(1, 0x09, 0x3f);

    // Powerup the Left and Right DAC Channels
    write(0, 0x3f, 0xd6);
    // Unmutethe DAC digital volume control 
    write(0, 0x40, 0x00);
    //sleep_ms(200);
    //printf("powering up adc, lets go\n");
    sleep_ms(10);
    //printf("powering up adc, now\n");
    // power up ADC
    write(0, 0x51, 0xc0);
    write(0, 0x52, 0x00);

    // enable headphone detection
    write(0, 0x43, 0x80);
}
void driver_set_hpvol(int8_t hpvol)
{
    // clamp to valid range
    if(hpvol < -6) hpvol = -6;
    if(hpvol > 29) hpvol = 29;
    write(1, 0x10, hpvol&0x3f);
    write(1, 0x11, hpvol&0x3f);
}

void driver_set_mute(bool mute)
{
    write(1, 0x10, mute?0x40:0x00);
    write(1, 0x11, mute?0x40:0x00);
}
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

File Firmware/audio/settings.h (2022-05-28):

// Copyright 2012 Emilie Gillet.
//
// Author: Emilie Gillet (emilie.o.gillet@gmail.com)
//
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
// See http://creativecommons.org/licenses/MIT/ for more information.
//
// -----------------------------------------------------------------------------
//
// Settings

#ifndef BRAIDS_SETTINGS_H_
#define BRAIDS_SETTINGS_H_

namespace braids {

const char* const algo_values[] = {
    "CSAW",
    "/\\-_",
    "//-_",
    "FOLD",
    "UUUU",
    "SUB-",
    "SUB/",
    "SYN-",
    "SYN/",
    "//x3",
    "-_x3",
    "/\\x3",
    "SIx3",
    "RING",
    "////",
    "TOY*",
    "ZLPF",
    "ZPKF",
    "ZBPF",
    "ZHPF",
    "VOSM",
    "VOWL",
    "VFOF",
    "HARM",
    "FM  ",
    "FBFM",
    "WTFM",
    "BELL",
    "DRUM",
    "KICK",
    "CYMB",
    "SNAR",
    "WTBL",
    "WMAP",
    "WLIN",
    "WTx4",
    "NOIS",
    "TWNQ",
    "CLKN",
    "CLOU",
    "PRTC",
    "QPSK",
    // "NAME" // For your algorithm
};

enum MacroOscillatorShape {
  MACRO_OSC_SHAPE_CSAW,
  MACRO_OSC_SHAPE_MORPH,
  MACRO_OSC_SHAPE_SAW_SQUARE,
  MACRO_OSC_SHAPE_SINE_TRIANGLE,
  MACRO_OSC_SHAPE_BUZZ,
  
  MACRO_OSC_SHAPE_SQUARE_SUB,
  MACRO_OSC_SHAPE_SAW_SUB,
  MACRO_OSC_SHAPE_SQUARE_SYNC,
  MACRO_OSC_SHAPE_SAW_SYNC,
  MACRO_OSC_SHAPE_TRIPLE_SAW,
  MACRO_OSC_SHAPE_TRIPLE_SQUARE,
  MACRO_OSC_SHAPE_TRIPLE_TRIANGLE,
  MACRO_OSC_SHAPE_TRIPLE_SINE,
  MACRO_OSC_SHAPE_TRIPLE_RING_MOD,
  MACRO_OSC_SHAPE_SAW_SWARM,
  MACRO_OSC_SHAPE_TOY,

  MACRO_OSC_SHAPE_DIGITAL_FILTER_LP,
  MACRO_OSC_SHAPE_DIGITAL_FILTER_PK,
  MACRO_OSC_SHAPE_DIGITAL_FILTER_BP,
  MACRO_OSC_SHAPE_DIGITAL_FILTER_HP,
  MACRO_OSC_SHAPE_VOSIM,
  MACRO_OSC_SHAPE_VOWEL,
  MACRO_OSC_SHAPE_VOWEL_FOF,
  
  MACRO_OSC_SHAPE_HARMONICS,

  MACRO_OSC_SHAPE_FM,
  MACRO_OSC_SHAPE_FEEDBACK_FM,
  MACRO_OSC_SHAPE_CHAOTIC_FEEDBACK_FM,

  MACRO_OSC_SHAPE_STRUCK_BELL,
  MACRO_OSC_SHAPE_STRUCK_DRUM,
  MACRO_OSC_SHAPE_KICK,
  MACRO_OSC_SHAPE_CYMBAL,
  MACRO_OSC_SHAPE_SNARE,

  MACRO_OSC_SHAPE_WAVETABLES,
  MACRO_OSC_SHAPE_WAVE_MAP,
  MACRO_OSC_SHAPE_WAVE_LINE,
  MACRO_OSC_SHAPE_WAVE_PARAPHONIC,

  MACRO_OSC_SHAPE_FILTERED_NOISE,
  MACRO_OSC_SHAPE_TWIN_PEAKS_NOISE,
  MACRO_OSC_SHAPE_CLOCKED_NOISE,
  MACRO_OSC_SHAPE_GRANULAR_CLOUD,
  MACRO_OSC_SHAPE_PARTICLE_NOISE,
  
  MACRO_OSC_SHAPE_DIGITAL_MODULATION,

  MACRO_OSC_SHAPE_QUESTION_MARK,
  // MACRO_OSC_SHAPE_YOUR_ALGO
  MACRO_OSC_SHAPE_LAST,
  MACRO_OSC_SHAPE_LAST_ACCESSIBLE_FROM_META = MACRO_OSC_SHAPE_DIGITAL_MODULATION
};

enum Resolution {
  RESOLUTION_2_BIT,
  RESOLUTION_3_BIT,
  RESOLUTION_4_BIT,
  RESOLUTION_6_BIT,
  RESOLUTION_8_BIT,
  RESOLUTION_12_BIT,
  RESOLUTION_16_BIT,
  RESOLUTION_LAST
};

enum SampleRate {
  SAMPLE_RATE_4K,
  SAMPLE_RATE_8K,
  SAMPLE_RATE_16K,
  SAMPLE_RATE_24k,
  SAMPLE_RATE_32k,
  SAMPLE_RATE_48K,
  SAMPLE_RATE_96K,
  SAMPLE_RATE_LAST
};

enum PitchRange {
  PITCH_RANGE_EXTERNAL,
  PITCH_RANGE_FREE,
  PITCH_RANGE_EXTENDED,
  PITCH_RANGE_440,
  PITCH_RANGE_LFO  // This setting is hidden by default!
};

enum Setting {
  SETTING_OSCILLATOR_SHAPE,
  SETTING_RESOLUTION,
  SETTING_SAMPLE_RATE,
  SETTING_AD_TIMBRE,
  SETTING_TRIG_SOURCE,
  SETTING_TRIG_DELAY,
  SETTING_META_MODULATION,
  SETTING_PITCH_RANGE,
  SETTING_PITCH_OCTAVE,
  SETTING_QUANTIZER_SCALE,
  SETTING_VCO_FLATTEN,
  SETTING_VCO_DRIFT,
  SETTING_SIGNATURE,
  SETTING_BRIGHTNESS,
  SETTING_AD_ATTACK,
  SETTING_AD_DECAY,
  SETTING_AD_FM,
  SETTING_AD_COLOR,
  SETTING_AD_VCA,
  SETTING_QUANTIZER_ROOT,
  SETTING_LAST_EDITABLE_SETTING = SETTING_QUANTIZER_ROOT,
  
  // Not settings per-se, but used for menu display!
  SETTING_CALIBRATION,
  SETTING_CV_TESTER,
  SETTING_MARQUEE,
  SETTING_VERSION,
  SETTING_LAST
};

struct SettingsData {
  uint8_t shape;
  uint8_t resolution;
  uint8_t sample_rate;
  uint8_t ad_timbre;
  uint8_t auto_trig;
  uint8_t trig_delay;
  uint8_t meta_modulation;
  uint8_t pitch_range;
  uint8_t pitch_octave;
  uint8_t quantizer_scale;
  uint8_t vco_flatten;
  uint8_t vco_drift;
  uint8_t signature;
  uint8_t brightness;
  uint8_t ad_attack;
  uint8_t ad_decay;
  uint8_t ad_fm;
  uint8_t ad_color;
  uint8_t ad_vca;
  uint8_t quantizer_root;
  
  int32_t pitch_cv_offset;
  int32_t pitch_cv_scale;
  int32_t fm_cv_offset;
  
  int16_t parameter_cv_offset[2];
  uint16_t parameter_cv_scale[2];
  
  char marquee_text[55];
  char magic_byte;
};

struct SettingMetadata {
  uint8_t min_value;
  uint8_t max_value;
  const char name[5];
  const char* const* strings;
  
  int16_t Clip(int16_t value) const {
    if (value > max_value) {
      value = max_value;
    } else if (value < min_value) {
      value = min_value;
    }
    return value;
  }
};
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

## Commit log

2019-12-30 initial hardware commit
    [backDrawing.dxf, quick.blend, tdm_frontboard.kicad_pcb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]
2020-04-02 playing around with samd11 for the frontboard, reworked power on the back
    [tdm_frontboard.sch, tdm_mainboard.sch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]
2020-04-02 added annotations to mainboard
    [tdm_mainboard.sch]
2020-04-03 some changes to the backboad
    [tdm_mainboard.kicad_pcb, tdm_mainboard.sch]
2020-04-09 fixed charlie plexed array
    [test_samd11.sch]
2021-09-19 removed old files, new schematic
    [ButtonsLEDS.sch, Power.sch, RK10J1_E.STEP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]
2021-11-25 update project with corrected schematic / pcb
    [ButtonsLEDS.sch, PCB_NEW_PCB_2021-10-03.kicad_pcb, Power.sch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]
2021-12-05 initial firmware commit, update hardware
    [ButtonsLEDS.sch, Power.sch, audioMidi.sch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]
2021-12-22 corrected core2 lockout behavior to work with flash fixed the sync buffer sizes in braids so the triple / suboscs work
    [main.cc]
2021-12-29 final v6 schematic
    [Power.sch, tdm_v6.kicad_pcb]
2021-12-31 new hardware rev
    - soft / latching power switch
    - corrected mic
    - added pullup to flash ss
    - front & back enclosure plates
    [ButtonsLEDS.sch, Power.sch, Screen.sch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]
2021-12-31 working on headphone detection, added filter
2021-12-31 added extra bom
2022-01-01 new midi instrument, corrected error in mixing routine
    [GrooveBox.h]
2022-01-02 patterns, chaining, and bugfix in drum instrument
    [GrooveBox.h]
2022-01-05 more features for the instrument new samples usb audio out bpm control
2022-01-17 LP default filter, better pattern display, added octaves
2022-01-22 fixed dac clock calculation
    [tlv320driver.c]
2022-01-27 corrected some hardware issues.
    [Power.sch, tdm_v6.kicad_pcb, tdm_v6.sch]
2022-02-05 new hardware rev
    reworked power system
    added amp
    new LDOS (less dropout)
    dedicated LDO for audio system
    [Power.sch, Screen.sch, audioMidi.sch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]
2022-02-10 corrected pcb / fixed c4 position
    [tdm_v6.kicad_pcb]
2022-04-04 started working on sampler
2022-04-30 sampling and sample playback working
2022-05-07 switched to parallel ws2812, serialization starting to work
2022-05-15 crappy midi out, don't erase on startup, LED refresh every frame
2022-05-25 uh, too much changed - this is v1 + some v2
    [GrooveBox.h, filesystem.h, hardware.c]
2022-05-27 fixed bug in filesize calculation, deserialization works
    [filesystem.h]
2022-06-04 switch to 32000, per pattern rates, corrected bpm
    [GrooveBox.h, filesystem.h, main.cc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]
2022-06-05 better sample recording / deletion
2022-06-09 add clear startup chord, correct voice count crash, voice stealing fix, slightly less clicking for sampler instruments
    [GrooveBox.h, filesystem.h]
2022-06-12 added microfades to the sampler
2022-06-12 schematic changes - not sure what
    [ButtonsLEDS.sch, Screen.sch, audioMidi.sch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]
2022-06-12 fixed up bpm, automatically split samples into 16 parts after sampling
    [GrooveBox.h, voice_data.h]
2022-06-26 don't know the state of things, just want to test out the new board, don't know how to stash.
2022-11-06 uhhh, just too many changes - most recently added the sample loop cutting
    [ButtonsLEDS.kicad_sch, Power.kicad_sch, Screen.kicad_sch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]
2022-12-24 v9 hardware
    [ButtonsLEDS.kicad_sch, Power.kicad_sch, Screen.kicad_sch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]
2022-12-28 lots of changes to the audio system
    seperate sends for delay & reverb
    correctly runs in release mode now
    fixed the signal to the other thread for screen refresh
    moved everything to use 64 samples instead of 128
    fixed the mic playthrough
    [GrooveBox.h, Reverb2.h, main.cc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]
2022-12-29 groovebox tweaks
    wait to switch patterns for global overflow
    switch back to 128 sample buffer length
2022-12-30 sync, fast shutdown, seperate sample env data
    cannot select "global" voice type
2022-12-30 sync out, dma midi
    sync output
    dma for midi output (non-blocking)
2022-12-31 fixed parameter lock pool exhaustion bug
    [Midi.cc, ParamLockPool.cpp, main.cc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]
2023-01-23 again, too many changes
    - fixed clipping
    - change bmp on the play button
    - midi keyboard works a bit better
    - keys not as bright
    - some nicer behavior in grid display
    - copy voices
    [GrooveBox.h, Midi.cc, main.cc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]
2023-01-23 working on different button ideas
    [buttonSurround.step, lightsurroundtest.FCStd, pipe.step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]
2023-01-26 parameter locks
    - clear param locks when clearing step
    - fix bug where instruments would look up non-existant parameter locks
    - show steps with parameter locks in a different color
    - fix up the voice data a little bit
    - disable some debug prints
    [main.cc, tlv320driver.c, voice_data.h]
2023-01-26 pitch target for envelopes, depth now displays -127-127
2023-01-29 cleanup main, better powerdown, better usbboot
2023-02-01 move global data to its own chunk
    remove unused parameters
    add in some nonsense
    move global parameters to outside buttons
2023-02-01 fixed channel 1 blinky lights
    [GrooveBox.h]
2023-02-02 too much again
    - auto shutdown
    - no appending to samples
    - fix up sampling displays
    - can record samples into track 16
    [GrooveBox.h, hardware.c, main.cc]
2023-02-18 added a warmup time in the turn on before setting the clock rate higher, fixes some hardware
    [hardware.c]
2023-02-18 interpolate the adc inputs
2023-03-18 patterns correctly roll over to the next pattern
    [GrooveBox.h]
2023-04-02 Added retriggers / switched to 96ppq
2023-04-08 v10 board
    [ButtonsLEDS.kicad_sch, Power.kicad_sch, Screen.kicad_sch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]
2023-04-08 corrected vias + updated schematic
    [tdm_v6.kicad_pcb]
2023-04-09 new faceplate
    [frontplate.kicad_pcb]
2023-04-24 setup everything to get ready for song files, wrote a migration from the old data (deleting the old filesystem stuff & cleaning out samples)
2023-04-24 fixed sample file ids
    [main.cc]
2023-04-28 corrected song write file, added "fast" delete
    [filesystem.h, main.cc]
2023-04-28 new 3d files
    [BackEnclosure.stl, Buttons.stl, FrontEnclosure.stl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]
2023-04-28 initial adc capture spends .5 seconds capturing
2023-04-29 fixed issue where I was getting offset adc values when gpio 29 was set to input
    [hardware.c]
2023-04-29 switch off pico probe to pico debug
2023-04-29 prusa slicer projects
    [BackEnclosure.3mf, Buttons.3mf]
2023-04-29 fixed midi out sync
    [GrooveBox.h]
2023-04-30 fix the lockout behavior again
    [main.cc]
2023-05-04 move usbserial init, fixed some screens, moved octave to per channel setting
    [main.cc]
2023-05-13 slower LFO, new LFO targets, fix retrigger, retrigger fade working
    [voice_data.h]
2023-05-14 move multicore to the correct spot and fully disable
    [main.cc]
2023-05-26 multicore processing for the audio, retriggers for samples cleanup, dma for the screen
2023-05-26 corrected the i2c pullups
    [tdm_v6.kicad_sch]
2023-07-02 move audio processing out of the interrupt, set it to process 2 64 length blocks
2023-07-04 v11 hardware
    [Power.kicad_sch, Screen.kicad_sch, tdm_v6.kicad_pcb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]
2023-07-04 fixed long standing issue in reverb! but the verb chorus effect is no longer working.
    [Reverb2.h]
2023-07-08 increase audio dma size again (256 now)
2024-04-05 pcb bodge fixes
    [Power.kicad_sch, audioMidi.kicad_sch, tdm_v6.kicad_pcb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]
2024-04-05 move to kicad8, rename kicad project
    [ButtonsLEDS.kicad_sch, ButtonsLEDS.sch, PCB_NEW_PCB_2021-10-03.kicad_pcb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]
2024-04-05 Add circuit python testing helpers
2024-04-05 updated frontplate
    [frontplate.kicad_pcb]
2024-04-05 update schematic doc block
    [ButtonsLEDS.kicad_sch, Power.kicad_sch, Screen.kicad_sch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]
2024-04-07 switched back to pico probe
2024-04-07 battery monitor & usb code
2024-04-08 fixed up bom for JLC
    [Power.kicad_sch, audcalc.kicad_pcb, audcalc.kicad_sch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]
2024-04-13 update faceplate
    [frontplate.kicad_pcb]
2024-04-13 updated layout
    [audcalc.kicad_pcb]
2024-04-14 store the playing pattern and the chain into the song data
2024-05-04 add startup delay to deal with instabilities on battery
2024-05-05 built out the back enclosure correctly
    [BackEnclosure.FCStd, BackEnclosure.stl]
2024-05-05 corrected voltage div / battery sense calculation
    [hardware.c]
2024-07-06 backcase with battery clip
    [BackEnclosure.FCStd]
2025-01-16 external sync mode fixed to support 4ppq and 2ppq
    [GrooveBox.h]
2025-09-16 update back enclosure with clips.
    [BackEnclosure.stl]
2025-12-05 update enclosure printing files
    [BackEnclosure.3mf, FrontEnclosure.3mf]
2025-12-05 instruction booklet printable
2026-03-23 updated to new sdk, fixed a parameter lock assert issue, task changed to work with vscode extension
    [Midi.cc, filesystem.h, main.cc]
2026-04-10 cleanup, fixed lock removal issues that was causing lock pool to be prematurely exhausted.
    [GrooveBox.h, ParamLockPool.cpp, filesystem.h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]
2026-07-17 move sample file writing to the second core
2026-08-18 updated PCB with new JLC part numbers
    [ButtonsLEDS.kicad_sch, Power.kicad_sch, Screen.kicad_sch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]
2026-08-20 find the actual head of the file when opening
    because blocks are allocated randomly, we could find the middle of a file and treat it as a head
    - causes corruption to the song files
    - incorrectly starts samples
    - incorrectly reports file size
2026-08-20 additional corruption checks
    check when reading, writing and opening for corrupt files. If save files are corrupt, creates a new file
    if audio samples are corrupt, returns zeros.
2026-08-20 fix up the file seeking and appending to be faster with extra helper pointers
    [filesystem.h]
2026-08-21 Midi input parser fixes (#6)
    bug fixes
    actually read the data correctly (lastCommand changes)
    realtime messages can be handled inside of non realtime (multi part) messages
    correctly set the message length depending on message type
    sysex messages are correctly ignored
    features
    midi cc mapping is working again.
    midi cc mapping notes
    to map a midi cc to a parameter, change the parameter that you want to map, then while holding the param button down change the midi cc - wiggle the knob on the external controller. These mappings are not saved, so they will be lost on shutdown. Also each CC can only be mapped to a single parameter, so if you map a cc to a different parameter, the first mapping is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
    [Midi.cc]
2026-08-21 fix midi note off sending and retriggers when sequencer is not playing.
    [GrooveBox.h, Midi.cc, voice_data.h]
2026-08-22 midi output improvements and other features
    - midi output note offs now send correctly when playing from the keys, even if sequencer is off
    - retriggers work correctly from the keys when sequencer is off
    - split midi voice from the regular voice so that all 16 midi voices are available, even if other voices are playing
    - usb descriptors are correct (audcalc / goblin group) and serial is set per board so you can have two connected to one computer
    - midi sending now tracks if note offs fail to send
    - midi sending now also tracks if it needs to send a cc value to update a channel - cached so we don't always blast out all the ccs
    [GrooveBox.h, Midi.cc]
2026-08-23 further midi / live play fixes
    - disconnecting usb midi no longer blocks trs midi
    - note hangs on channel change fixed
    - read the current patterns rate when live playing keys
    - locks don't leak from step zero into the played live keys
    - cleanup of the voice_data parameter lookups
    [Midi.cc, SequencedVoice.h]
2026-08-30 corrected display of the reverb settings
    [Reverb2.h]
